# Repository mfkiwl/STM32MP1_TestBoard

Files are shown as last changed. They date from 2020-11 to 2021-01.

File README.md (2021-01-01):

### STM32MP1 Embedded Linux breakout board ###

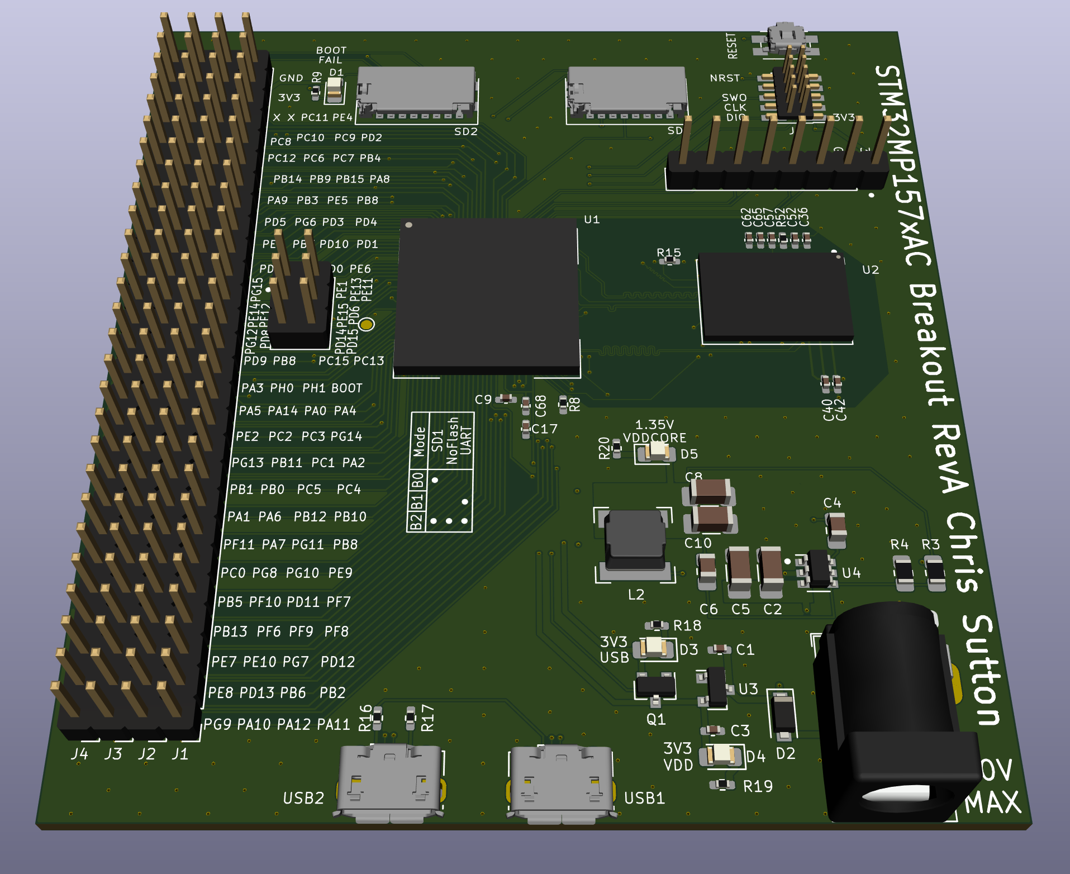
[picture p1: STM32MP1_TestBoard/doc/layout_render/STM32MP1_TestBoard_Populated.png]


[Bill of materials](STM32MP1_TestBoard/doc/bom/STM32MP1_TestBoard.csv)

[DataSheets](STM32MP1_TestBoard/doc/datasheets)

#### System Overview ####


#### Power Supply ####


#### MPU Power Supply ####


#### MPU DDR ####


#### MicroSD connectors ####


#### USB Connectors ####


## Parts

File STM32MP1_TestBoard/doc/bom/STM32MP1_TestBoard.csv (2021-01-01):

Reference | Value | Footprint | Datasheet | Mfr | PartNo
C17 | 1uF | Capacitor_SMD:C_0402_1005Metric_Pad0.74x0.62mm_HandSolder | https://datasheet.lcsc.com/szlcsc/1810201223_Taiyo-Yuden-LMK105BJ105KV-F_C87145.pdf | Taiyo Yuden | LMK105BJ105KV-F
C18 | 1uF | Capacitor_SMD:C_0402_1005Metric_Pad0.74x0.62mm_HandSolder | https://datasheet.lcsc.com/szlcsc/1810201223_Taiyo-Yuden-LMK105BJ105KV-F_C87145.pdf | Taiyo Yuden | LMK105BJ105KV-F
C21 | 1uF | Capacitor_SMD:C_0402_1005Metric_Pad0.74x0.62mm_HandSolder | https://datasheet.lcsc.com/szlcsc/1810201223_Taiyo-Yuden-LMK105BJ105KV-F_C87145.pdf | Taiyo Yuden | LMK105BJ105KV-F
C24 | 1uF | Capacitor_SMD:C_0402_1005Metric_Pad0.74x0.62mm_HandSolder | https://datasheet.lcsc.com/szlcsc/1810201223_Taiyo-Yuden-LMK105BJ105KV-F_C87145.pdf | Taiyo Yuden | LMK105BJ105KV-F
C27 | 1uF | Capacitor_SMD:C_0402_1005Metric_Pad0.74x0.62mm_HandSolder | https://datasheet.lcsc.com/szlcsc/1810201223_Taiyo-Yuden-LMK105BJ105KV-F_C87145.pdf | Taiyo Yuden | LMK105BJ105KV-F
C30 | 1uF | Capacitor_SMD:C_0402_1005Metric_Pad0.74x0.62mm_HandSolder | https://datasheet.lcsc.com/szlcsc/1810201223_Taiyo-Yuden-LMK105BJ105KV-F_C87145.pdf | Taiyo Yuden | LMK105BJ105KV-F
C32 | 1uF | Capacitor_SMD:C_0402_1005Metric_Pad0.74x0.62mm_HandSolder | https://datasheet.lcsc.com/szlcsc/1810201223_Taiyo-Yuden-LMK105BJ105KV-F_C87145.pdf | Taiyo Yuden | LMK105BJ105KV-F
C34 | 1uF | Capacitor_SMD:C_0402_1005Metric_Pad0.74x0.62mm_HandSolder | https://datasheet.lcsc.com/szlcsc/1810201223_Taiyo-Yuden-LMK105BJ105KV-F_C87145.pdf | Taiyo Yuden | LMK105BJ105KV-F
C35 | 1uF | Capacitor_SMD:C_0402_1005Metric_Pad0.74x0.62mm_HandSolder | https://datasheet.lcsc.com/szlcsc/1810201223_Taiyo-Yuden-LMK105BJ105KV-F_C87145.pdf | Taiyo Yuden | LMK105BJ105KV-F
C19 | 1uF | Capacitor_SMD:C_0402_1005Metric_Pad0.74x0.62mm_HandSolder | https://datasheet.lcsc.com/szlcsc/1810201223_Taiyo-Yuden-LMK105BJ105KV-F_C87145.pdf | Taiyo Yuden | LMK105BJ105KV-F
C22 | 1uF | Capacitor_SMD:C_0402_1005Metric_Pad0.74x0.62mm_HandSolder | https://datasheet.lcsc.com/szlcsc/1810201223_Taiyo-Yuden-LMK105BJ105KV-F_C87145.pdf | Taiyo Yuden | LMK105BJ105KV-F
C25 | 1uF | Capacitor_SMD:C_0402_1005Metric_Pad0.74x0.62mm_HandSolder | https://datasheet.lcsc.com/szlcsc/1810201223_Taiyo-Yuden-LMK105BJ105KV-F_C87145.pdf | Taiyo Yuden | LMK105BJ105KV-F
C28 | 1uF | Capacitor_SMD:C_0402_1005Metric_Pad0.74x0.62mm_HandSolder | https://datasheet.lcsc.com/szlcsc/1810201223_Taiyo-Yuden-LMK105BJ105KV-F_C87145.pdf | Taiyo Yuden | LMK105BJ105KV-F
C31 | 1uF | Capacitor_SMD:C_0402_1005Metric_Pad0.74x0.62mm_HandSolder | https://datasheet.lcsc.com/szlcsc/1810201223_Taiyo-Yuden-LMK105BJ105KV-F_C87145.pdf | Taiyo Yuden | LMK105BJ105KV-F
C33 | 1uF | Capacitor_SMD:C_0402_1005Metric_Pad0.74x0.62mm_HandSolder | https://datasheet.lcsc.com/szlcsc/1810201223_Taiyo-Yuden-LMK105BJ105KV-F_C87145.pdf | Taiyo Yuden | LMK105BJ105KV-F
C20 | 1uF | Capacitor_SMD:C_0402_1005Metric_Pad0.74x0.62mm_HandSolder | https://datasheet.lcsc.com/szlcsc/1810201223_Taiyo-Yuden-LMK105BJ105KV-F_C87145.pdf | Taiyo Yuden | LMK105BJ105KV-F
C23 | 1uF | Capacitor_SMD:C_0402_1005Metric_Pad0.74x0.62mm_HandSolder | https://datasheet.lcsc.com/szlcsc/1810201223_Taiyo-Yuden-LMK105BJ105KV-F_C87145.pdf | Taiyo Yuden | LMK105BJ105KV-F
C26 | 1uF | Capacitor_SMD:C_0402_1005Metric_Pad0.74x0.62mm_HandSolder | https://datasheet.lcsc.com/szlcsc/1810201223_Taiyo-Yuden-LMK105BJ105KV-F_C87145.pdf | Taiyo Yuden | LMK105BJ105KV-F
C29 | 1uF | Capacitor_SMD:C_0402_1005Metric_Pad0.74x0.62mm_HandSolder | https://datasheet.lcsc.com/szlcsc/1810201223_Taiyo-Yuden-LMK105BJ105KV-F_C87145.pdf | Taiyo Yuden | LMK105BJ105KV-F
L3 | LQM18FN4R7M00D | Inductor_SMD:L_0201_0603Metric_Pad0.64x0.40mm_HandSolder | https://www.mouser.co.uk/datasheet/2/281/JELF243B-0012-1633801.pdf | ~ | ~
C14 | 1uF | Capacitor_SMD:C_0402_1005Metric_Pad0.74x0.62mm_HandSolder | https://datasheet.lcsc.com/szlcsc/1810201223_Taiyo-Yuden-LMK105BJ105KV-F_C87145.pdf | Taiyo Yuden | LMK105BJ105KV-F
C12 | 1uF | Capacitor_SMD:C_0402_1005Metric_Pad0.74x0.62mm_HandSolder | https://datasheet.lcsc.com/szlcsc/1810201223_Taiyo-Yuden-LMK105BJ105KV-F_C87145.pdf | Taiyo Yuden | LMK105BJ105KV-F
JP4 | Jumper_NC_Small | Jumper:SolderJumper-2_P1.3mm_Bridged_Pad1.0x1.5mm | ~ | ~ | ~
C69 | 2.2uF | Capacitor_SMD:C_0402_1005Metric_Pad0.74x0.62mm_HandSolder | https://datasheet.lcsc.com/szlcsc/1810201223_Taiyo-Yuden-LMK105BJ105KV-F_C87145.pdf | Taiyo Yuden | LMK105BJ105KV-F
C70 | 1uF | Capacitor_SMD:C_0402_1005Metric_Pad0.74x0.62mm_HandSolder | https://datasheet.lcsc.com/szlcsc/1810201223_Taiyo-Yuden-LMK105BJ105KV-F_C87145.pdf | Taiyo Yuden | LMK105BJ105KV-F
C68 | 1uF | Capacitor_SMD:C_0402_1005Metric_Pad0.74x0.62mm_HandSolder | https://datasheet.lcsc.com/szlcsc/1810201223_Taiyo-Yuden-LMK105BJ105KV-F_C87145.pdf | Taiyo Yuden | LMK105BJ105KV-F
C7 | 2.2uF | Capacitor_SMD:C_0402_1005Metric_Pad0.74x0.62mm_HandSolder | https://datasheet.lcsc.com/szlcsc/1810201223_Taiyo-Yuden-LMK105BJ105KV-F_C87145.pdf | Taiyo Yuden | LMK105BJ105KV-F
C9 | 2.2uF | Capacitor_SMD:C_0402_1005Metric_Pad0.74x0.62mm_HandSolder | https://datasheet.lcsc.com/szlcsc/1810201223_Taiyo-Yuden-LMK105BJ105KV-F_C87145.pdf | Taiyo Yuden | LMK105BJ105KV-F
U1 | STM32MP157xAC | STM32MP151_LFBGA:BGA-361_19x19_16.0x16.0mm | https://www.st.com/resource/en/datasheet/stm32mp151c.pdf | ~ | ~
TP1 | TestPoint | TestPoint:TestPoint_Pad_D1.0mm | ~ | ~ | ~
U4 | TPS54202DDC | Package_TO_SOT_SMD:SOT-23-6 | http://www.ti.com/lit/ds/symlink/tps54202.pdf | Texas Instruments | TPS54202DDCR
C2 | 22uF | Capacitor_SMD:C_1206_3216Metric_Pad1.33x1.80mm_HandSolder | https://www.mouser.co.uk/datasheet/2/212/KEM_C1006_X5R_SMD-1103249.pdf | Kemet | C1206C226M8PACTU
C8 | 22uF | Capacitor_SMD:C_1206_3216Metric_Pad1.33x1.80mm_HandSolder | https://www.mouser.co.uk/datasheet/2/212/KEM_C1006_X5R_SMD-1103249.pdf | Kemet | C1206C226M8PACTU
C10 | 22uF | Capacitor_SMD:C_1206_3216Metric_Pad1.33x1.80mm_HandSolder | https://www.mouser.co.uk/datasheet/2/212/KEM_C1006_X5R_SMD-1103249.pdf | Kemet | C1206C226M8PACTU
L2 | 4.7uH | Inductor_SMD:L_Bourns-SRN6028 | https://datasheet.lcsc.com/szlcsc/1808311234_SXN-Shun-Xiang-Nuo-Elec-SMNR6028-4R7MT_C266428.pdf | Shun Xiang Nuo Elec | SMNR6028-4R7MT
C4 | 100nF | Capacitor_SMD:C_0805_2012Metric_Pad1.18x1.45mm_HandSolder | ~ | ~ | ~
C6 | 56pF | Capacitor_SMD:C_0805_2012Metric_Pad1.18x1.45mm_HandSolder | ~ | ~ | ~
R3 | 100K | Resistor_SMD:R_0805_2012Metric_Pad1.20x1.40mm_HandSolder | ~ | ~ | ~
R4 | 82K | Resistor_SMD:R_0805_2012Metric_Pad1.20x1.40mm_HandSolder | ~ | ~ | ~
Q1 | DMG2302U | Package_TO_SOT_SMD:SOT-23 | https://datasheet.octopart.com/DMG2302U-7-Diodes-Inc.-datasheet-103571615.pdf | DiodesInc | DMG2302U
U3 | SE8233X2 | Package_TO_SOT_SMD:SOT-23 | https://datasheet.lcsc.com/szlcsc/1912111437_Seaward-Elec-SE8233X2_C437587.pdf | ~ | ~
C1 | 1uF | Capacitor_SMD:C_0402_1005Metric_Pad0.74x0.62mm_HandSolder | ~ | ~ | ~
C3 | 10uF | Capacitor_SMD:C_0402_1005Metric_Pad0.74x0.62mm_HandSolder | ~ | ~ | ~
C5 | 22uF | Capacitor_SMD:C_1206_3216Metric_Pad1.33x1.80mm_HandSolder | https://www.mouser.co.uk/datasheet/2/212/KEM_C1006_X5R_SMD-1103249.pdf | Kemet | C1206C226M8PACTU
J9 | Barrel_Jack | Connector_BarrelJack:BarrelJack_Horizontal | ~ | ~ | ~
D2 | D_Schottky | Diode_SMD:D_SOD-123F | ~ | ~ | ~
D4 | LED | LED_SMD:LED_0805_2012Metric_Pad1.15x1.40mm_HandSolder | ~ | ~ | ~
R19 | 2K2 | Resistor_SMD:R_0402_1005Metric_Pad0.72x0.64mm_HandSolder | ~ | ~ | ~
D5 | LED | LED_SMD:LED_0805_2012Metric_Pad1.15x1.40mm_HandSolder | ~ | ~ | ~
R20 | 2K2 | Resistor_SMD:R_0402_1005Metric_Pad0.72x0.64mm_HandSolder | ~ | ~ | ~
D3 | LED | LED_SMD:LED_0805_2012Metric_Pad1.15x1.40mm_HandSolder | ~ | ~ | ~
R18 | 2K2 | Resistor_SMD:R_0402_1005Metric_Pad0.72x0.64mm_HandSolder | ~ | ~ | ~
SW2 | SW_SPST | Button_Switch_SMD:Panasonic_EVQPUK_EVQPUB | https://industrial.panasonic.com/cdbs/www-data/pdf/ATK0000/ATK0000C382.pdf | ~ | ~
C13 | 10nF | Capacitor_SMD:C_0402_1005Metric_Pad0.74x0.62mm_HandSolder | ~ | ~ | ~
C15 | 10nF | Capacitor_SMD:C_0402_1005Metric_Pad0.74x0.62mm_HandSolder | ~ | ~ | ~
JP5 | Jumper_NC_Small | Jumper:SolderJumper-2_P1.3mm_Bridged_RoundedPad1.0x1.5mm | ~ | ~ | ~
J6 | Conn_02x05_Odd_Even | Connector_PinHeader_1.27mm:PinHeader_2x05_P1.27mm_Vertical_SMD | https://docs.rs-online.com/75e3/0900766b8142184e.pdf | Amphenol ICC | 20021121-00010C4LF
J5 | Conn_02x03_Odd_Even | Connector_PinHeader_2.54mm:PinHeader_2x03_P2.54mm_Vertical | ~ | ~ | ~
R7 | 1K | Resistor_SMD:R_0402_1005Metric_Pad0.72x0.64mm_HandSolder | ~ | ~ | ~
R5 | 1K | Resistor_SMD:R_0402_1005Metric_Pad0.72x0.64mm_HandSolder | ~ | ~ | ~
R1 | 1K | Resistor_SMD:R_0402_1005Metric_Pad0.72x0.64mm_HandSolder | ~ | ~ | ~
R8 | 3K | Resistor_SMD:R_0402_1005Metric_Pad0.72x0.64mm_HandSolder | ~ | ~ | ~
D1 | LED | LED_SMD:LED_0805_2012Metric_Pad1.15x1.40mm_HandSolder | ~ | ~ | ~
R9 | 1K | Resistor_SMD:R_0402_1005Metric_Pad0.72x0.64mm_HandSolder | ~ | ~ | ~
J1 | Conn_01x27 | Connector_PinHeader_2.54mm:PinHeader_1x27_P2.54mm_Vertical | ~ | ~ | ~
J3 | Conn_01x27 | Connector_PinHeader_2.54mm:PinHeader_1x27_P2.54mm_Vertical | ~ | ~ | ~
J4 | Conn_01x27 | Connector_PinHeader_2.54mm:PinHeader_1x27_P2.54mm_Vertical | ~ | ~ | ~
J2 | Conn_01x27 | Connector_PinHeader_2.54mm:PinHeader_1x27_P2.54mm_Vertical | ~ | ~ | ~
J7 | Conn_01x08 | Connector_PinHeader_2.54mm:PinHeader_1x08_P2.54mm_Vertical | ~ | ~ | ~
R12 | 47K | Resistor_SMD:R_0402_1005Metric_Pad0.72x0.64mm_HandSolder | ~ | ~ | ~
R13 | 47K | Resistor_SMD:R_0402_1005Metric_Pad0.72x0.64mm_HandSolder | ~ | ~ | ~
R40 | 47K | Resistor_SMD:R_0402_1005Metric_Pad0.72x0.64mm_HandSolder | ~ | ~ | ~
R41 | 47K | Resistor_SMD:R_0402_1005Metric_Pad0.72x0.64mm_HandSolder | ~ | ~ | ~
R42 | 47K | Resistor_SMD:R_0402_1005Metric_Pad0.72x0.64mm_HandSolder | ~ | ~ | ~
J12 | Micro_SD_Card | Molex_SDIO:Molex_SDIO_475710001 | https://www.molex.com/molex/products/part-detail/memory_card_socket/0475710001 | Molex | 475710001
J14 | USB_B_Micro | Connector_USB:USB_Micro-B_Molex-105017-0001 | ~ | ~ | ~
J8 | USB_B_Micro | Connector_USB:USB_Micro-B_Molex-105017-0001 | ~ | ~ | ~
R16 | 0R | Resistor_SMD:R_0402_1005Metric_Pad0.72x0.64mm_HandSolder | ~ | ~ | ~
R17 | 0R | Resistor_SMD:R_0402_1005Metric_Pad0.72x0.64mm_HandSolder | ~ | ~ | ~
R43 | 47K | Resistor_SMD:R_0402_1005Metric_Pad0.72x0.64mm_HandSolder | ~ | ~ | ~
R44 | 47K | Resistor_SMD:R_0402_1005Metric_Pad0.72x0.64mm_HandSolder | ~ | ~ | ~
R45 | 47K | Resistor_SMD:R_0402_1005Metric_Pad0.72x0.64mm_HandSolder | ~ | ~ | ~
R46 | 47K | Resistor_SMD:R_0402_1005Metric_Pad0.72x0.64mm_HandSolder | ~ | ~ | ~
R47 | 47K | Resistor_SMD:R_0402_1005Metric_Pad0.72x0.64mm_HandSolder | ~ | ~ | ~
J13 | Micro_SD_Card | Molex_SDIO:Molex_SDIO_475710001 | https://www.molex.com/molex/products/part-detail/memory_card_socket/0475710001 | Molex | 475710001
U2 | MT41K256M16TW-107 | Package_BGA:BGA-96_9.0x13.0mm_Layout2x3x16_P0.8mm | https://www.mouser.co.uk/datasheet/2/671/4Gb_DDR3L-1283964.pdf | Micron | MT41K256M16TW-107
C36 | 100nF | Capacitor_SMD:C_0402_1005Metric_Pad0.74x0.62mm_HandSolder | ~ | ~ | ~
R10 | 240R | Resistor_SMD:R_0402_1005Metric_Pad0.72x0.64mm_HandSolder | ~ | ~ | ~
R11 | 240R | Resistor_SMD:R_0402_1005Metric_Pad0.72x0.64mm_HandSolder | ~ | ~ | ~
R6 | 10K | Resistor_SMD:R_0402_1005Metric_Pad0.72x0.64mm_HandSolder | ~ | ~ | ~
R15 | 10K | Resistor_SMD:R_0402_1005Metric_Pad0.72x0.64mm_HandSolder | ~ | ~ | ~
R14 | 100R | Resistor_SMD:R_0402_1005Metric_Pad0.72x0.64mm_HandSolder | ~ | ~ | ~
C52 | 100nF | Capacitor_SMD:C_0402_1005Metric_Pad0.74x0.62mm_HandSolder | ~ | ~ | ~
C57 | 100nF | Capacitor_SMD:C_0402_1005Metric_Pad0.74x0.62mm_HandSolder | ~ | ~ | ~
C62 | 100nF | Capacitor_SMD:C_0402_1005Metric_Pad0.74x0.62mm_HandSolder | ~ | ~ | ~
C65 | 100nF | Capacitor_SMD:C_0402_1005Metric_Pad0.74x0.62mm_HandSolder | ~ | ~ | ~
C43 | 100nF | Capacitor_SMD:C_0402_1005Metric_Pad0.74x0.62mm_HandSolder | ~ | ~ | ~
C42 | 100nF | Capacitor_SMD:C_0402_1005Metric_Pad0.74x0.62mm_HandSolder | ~ | ~ | ~
C41 | 100nF | Capacitor_SMD:C_0402_1005Metric_Pad0.74x0.62mm_HandSolder | ~ | ~ | ~
C40 | 100nF | Capacitor_SMD:C_0402_1005Metric_Pad0.74x0.62mm_HandSolder | ~ | ~ | ~
R2 | 1K | Resistor_SMD:R_0402_1005Metric_Pad0.72x0.64mm_HandSolder | ~ | ~ | ~
R52 | 1K | Resistor_SMD:R_0402_1005Metric_Pad0.72x0.64mm_HandSolder | ~ | ~ | ~

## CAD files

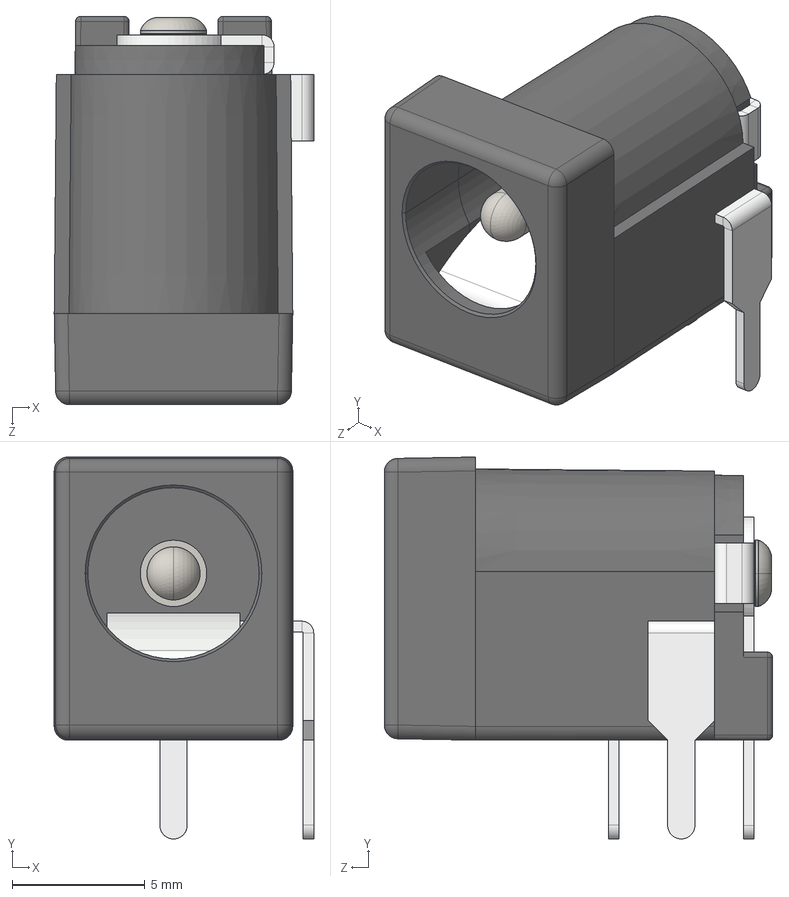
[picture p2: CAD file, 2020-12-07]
STM32MP1_TestBoard/doc/3d/DC Power Jack 5.5mm x 2.1mm.STEP
9.77 x 14.4 x 14.6 mm

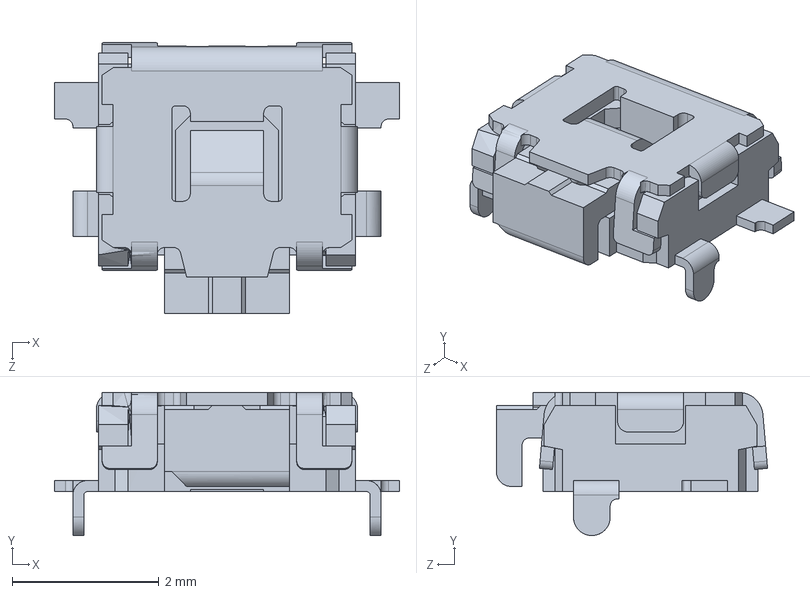
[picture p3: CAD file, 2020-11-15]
STM32MP1_TestBoard/doc/3d/EVQ-9P7_P34-01P.STEP
4.70 x 1.95 x 3.69 mm

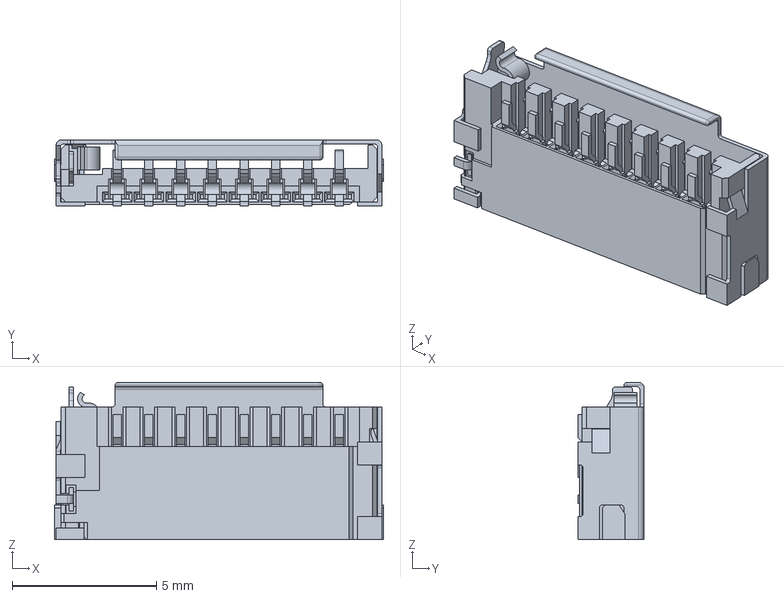
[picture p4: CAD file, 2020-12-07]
STM32MP1_TestBoard/doc/3d/475710001.stp
11.4 x 2.30 x 5.45 mm

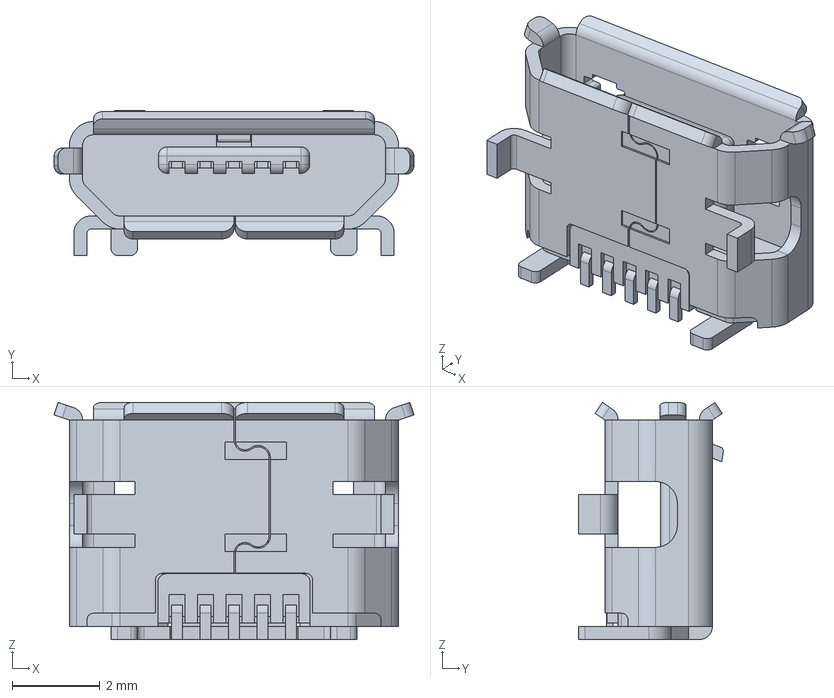
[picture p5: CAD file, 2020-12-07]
STM32MP1_TestBoard/doc/3d/1050170001.stp
8.20 x 3.30 x 5.40 mm

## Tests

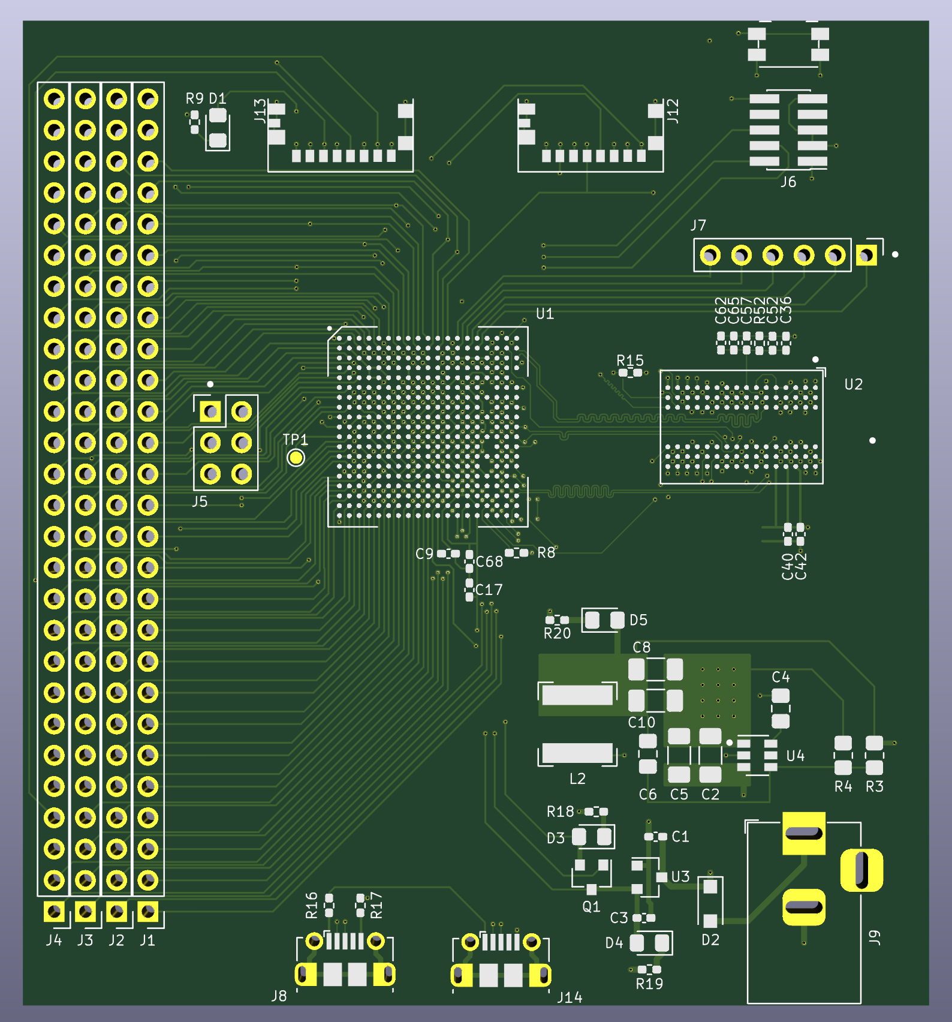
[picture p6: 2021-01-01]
STM32MP1_TestBoard/doc/layout_render/STM32MP1_TestBoard_Front.png

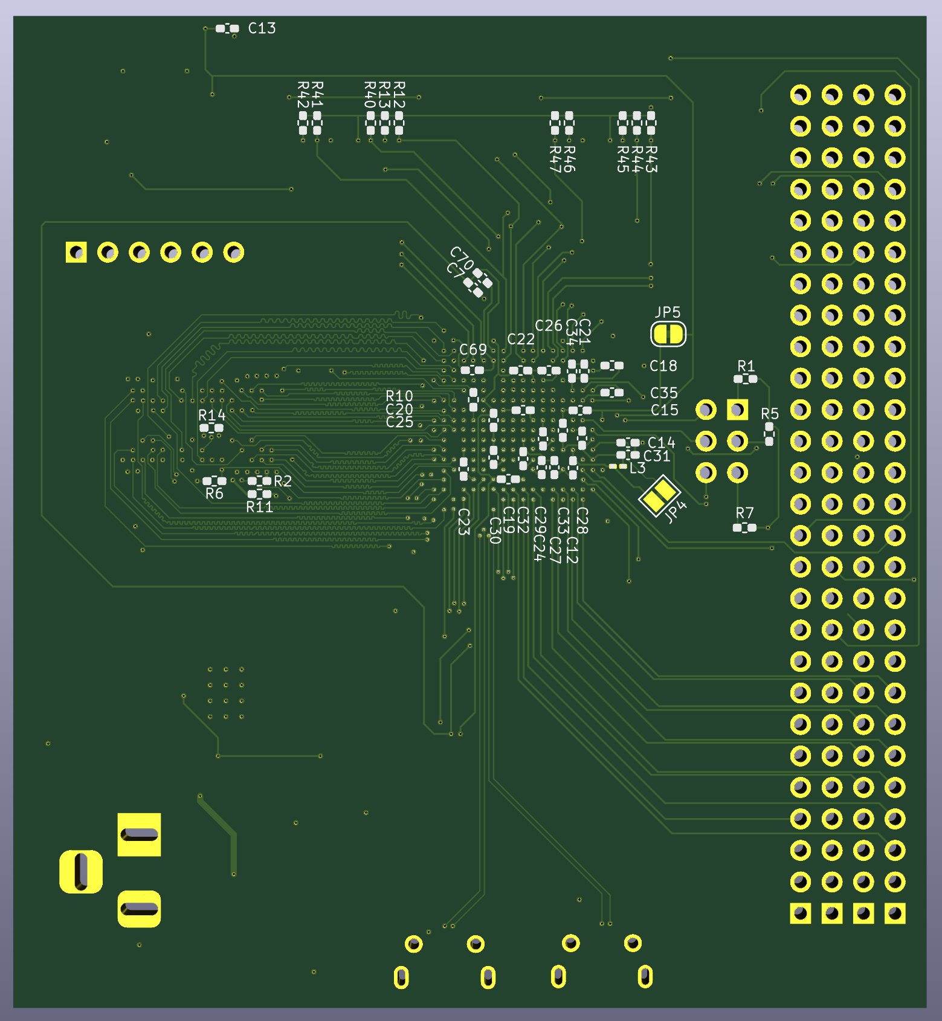
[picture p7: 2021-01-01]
STM32MP1_TestBoard/doc/layout_render/STM32MP1_TestBoard_Back.png

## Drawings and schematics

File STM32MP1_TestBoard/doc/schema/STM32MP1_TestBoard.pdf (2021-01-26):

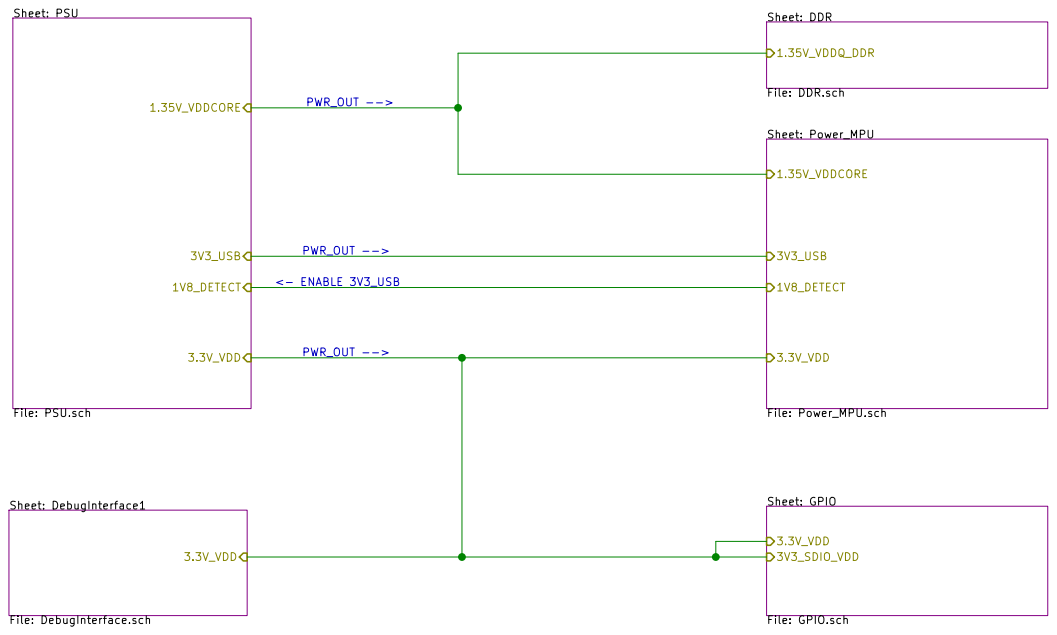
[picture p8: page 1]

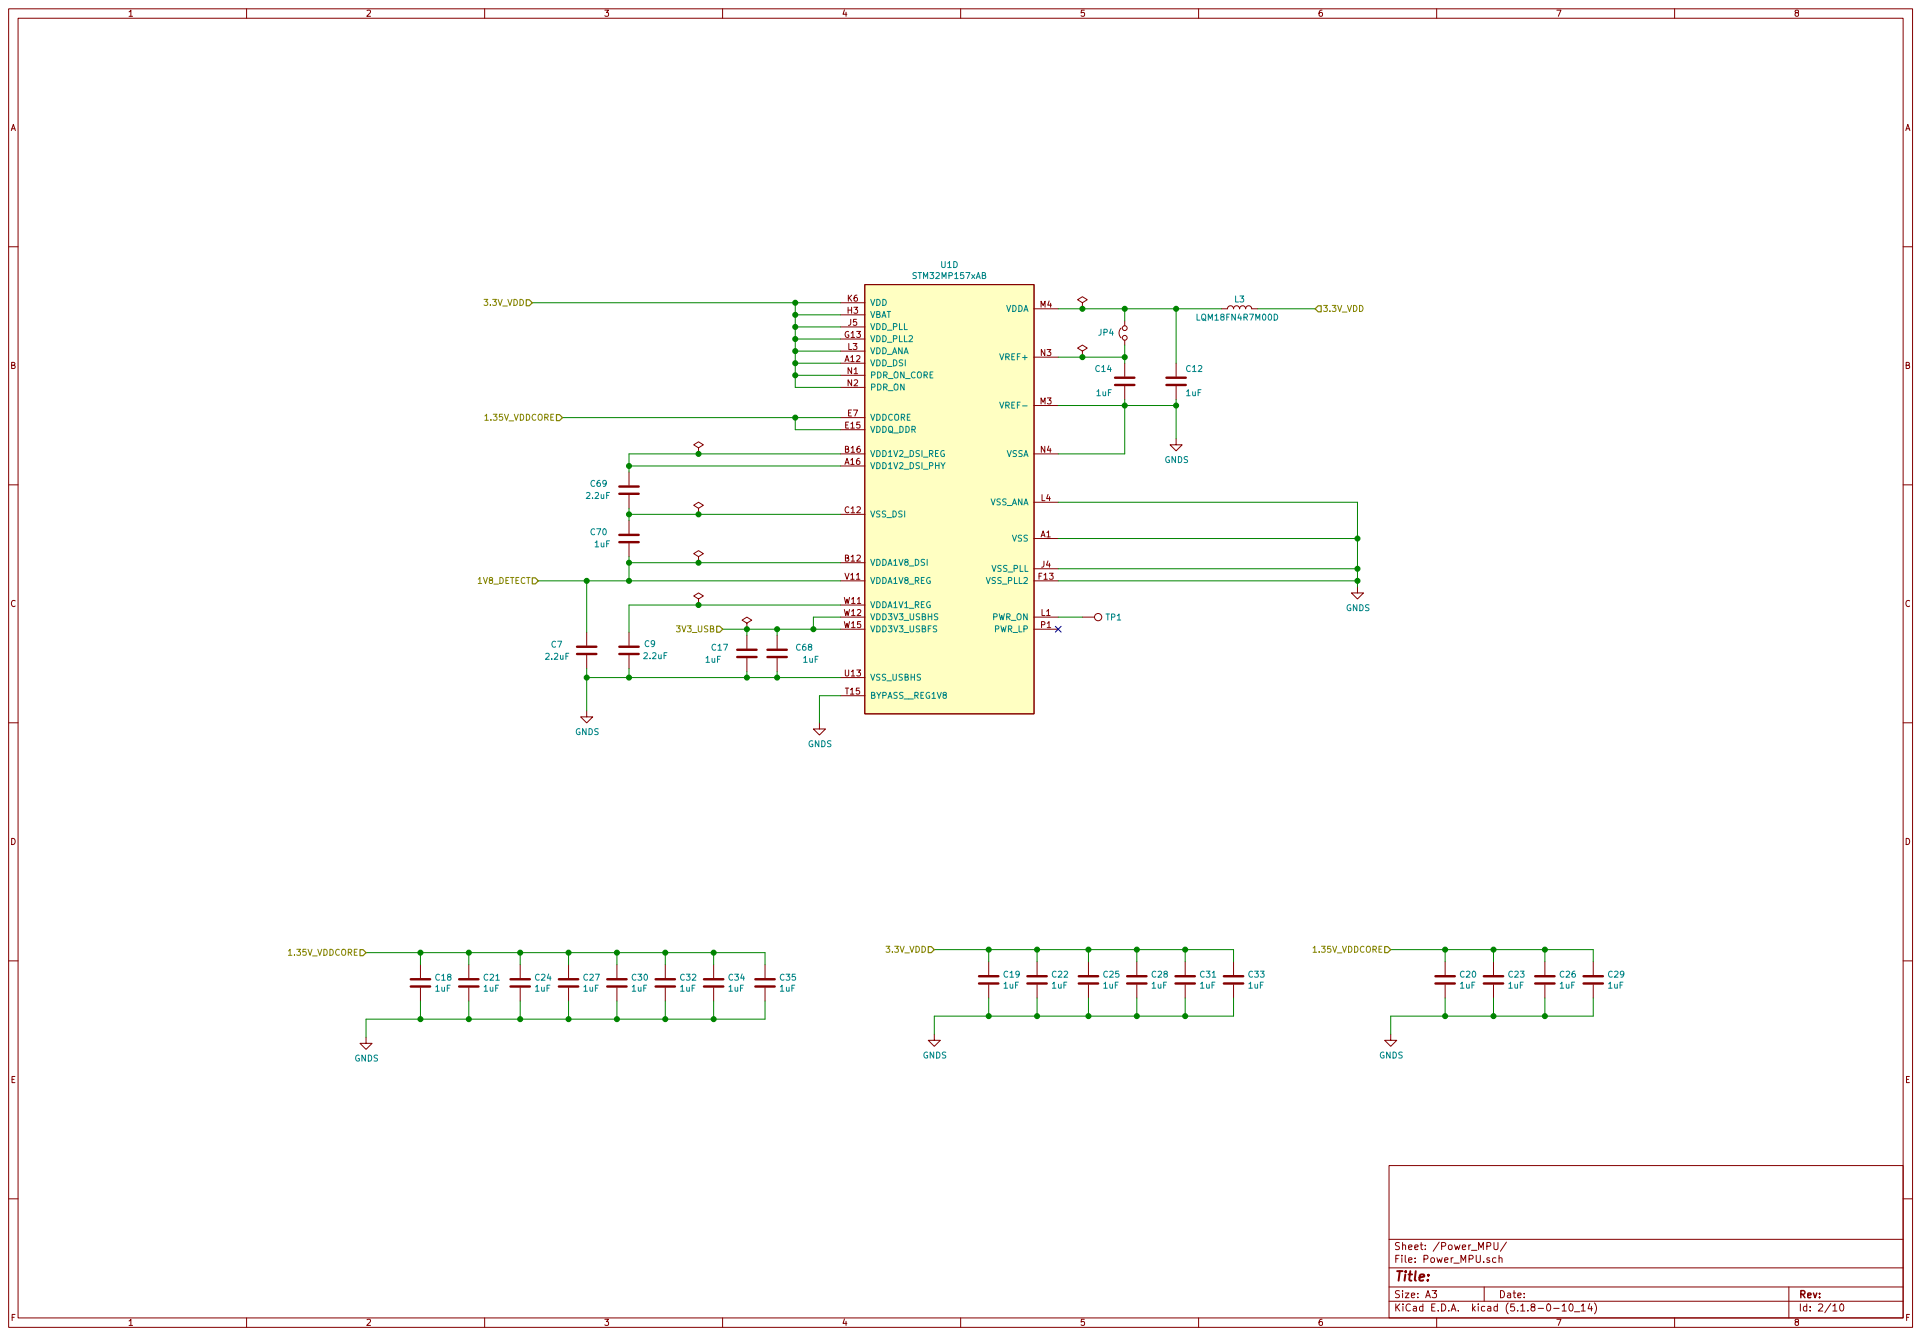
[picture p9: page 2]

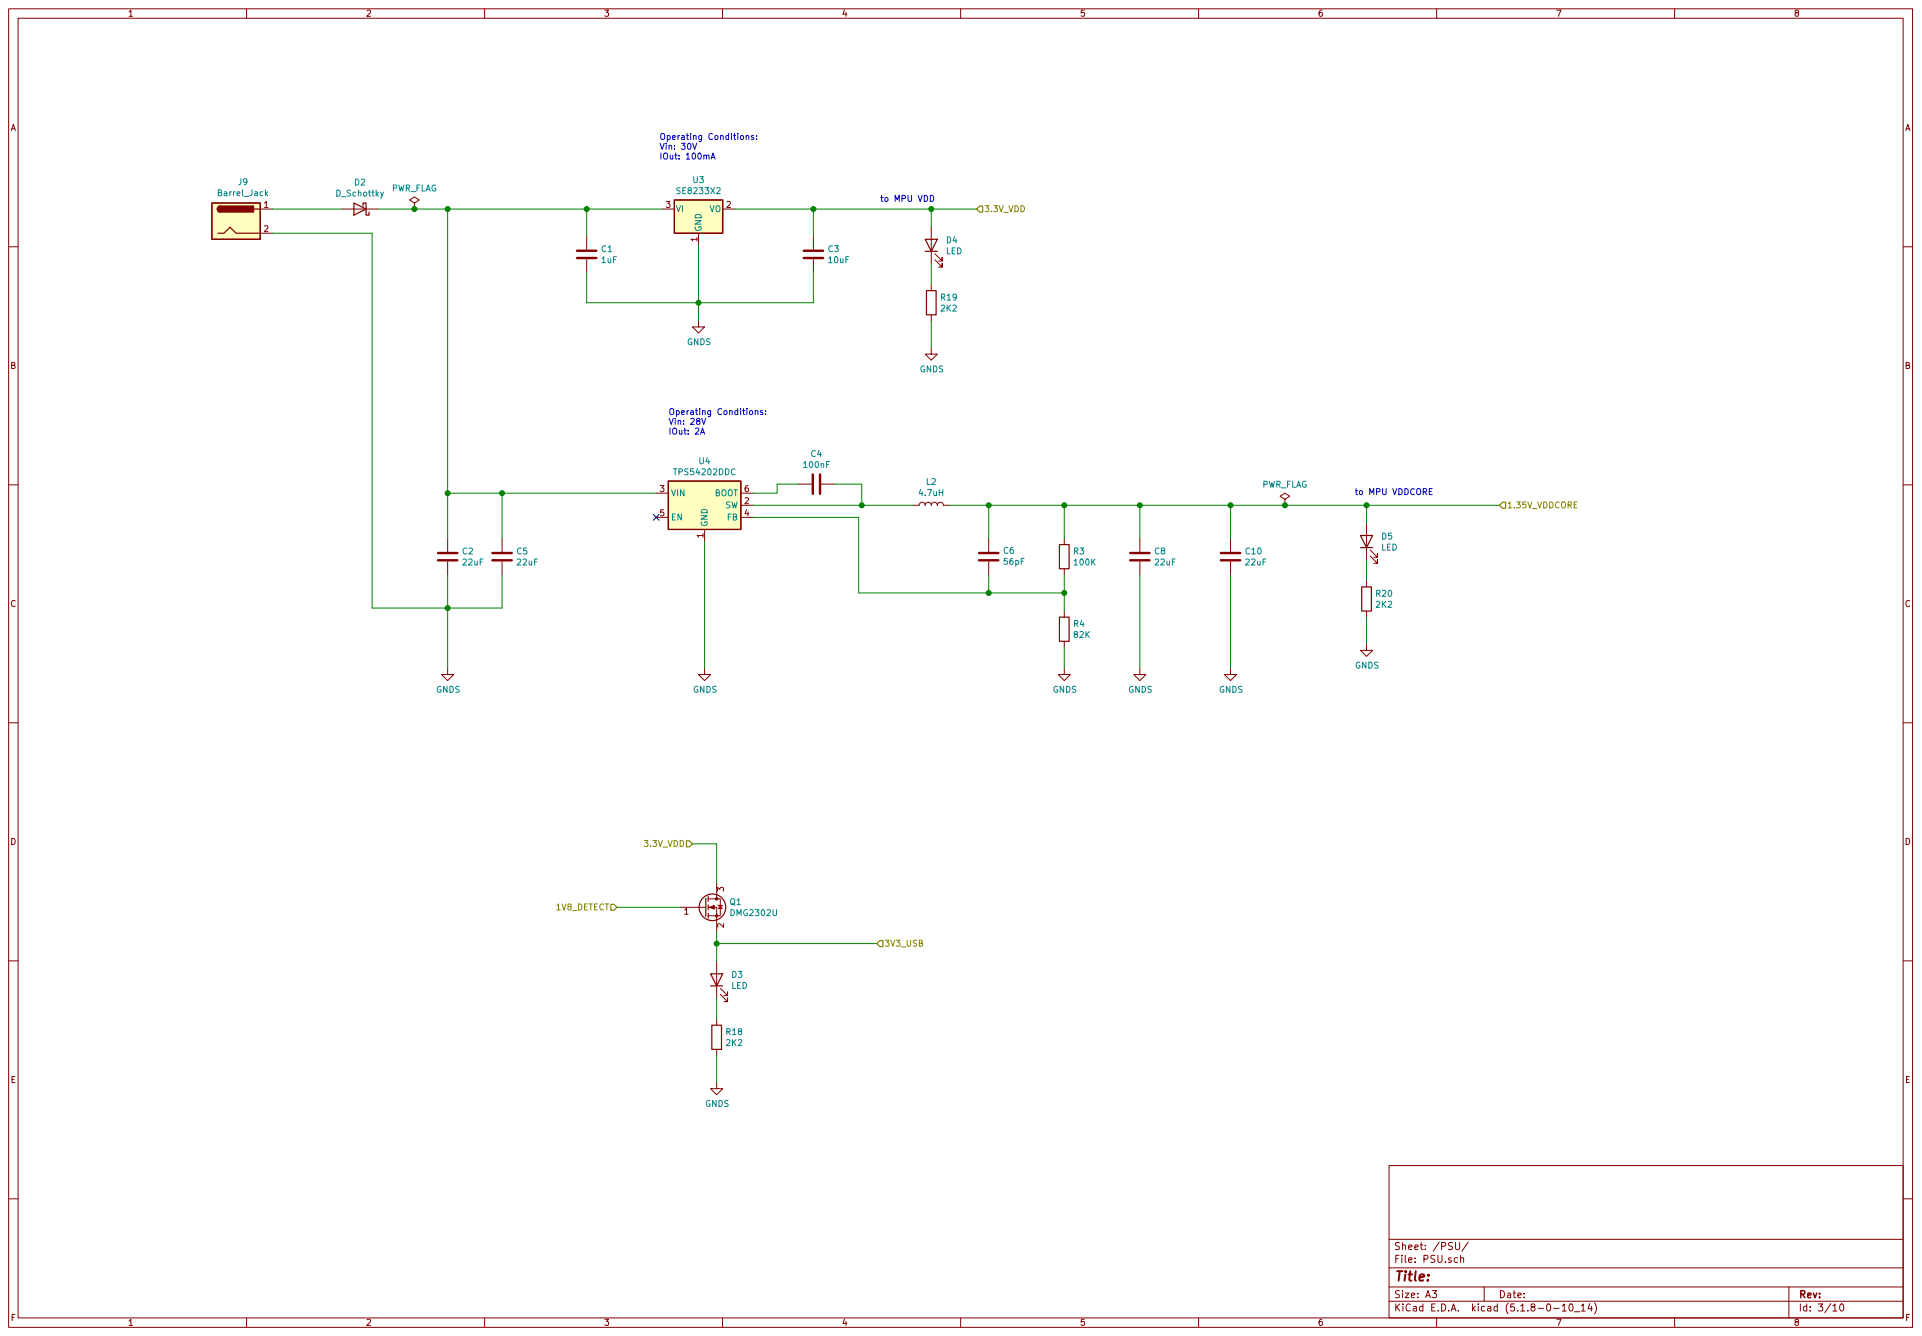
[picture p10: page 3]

IOut: 2A Operating Conditions: Vin: 30V

1 SW 2 VIN 3 FB 4 EN 5 BOOT 6 U4 TPS54202DDC

Id: 3/10 Title: File: PSU.sch Sheet: /PSU/ GND

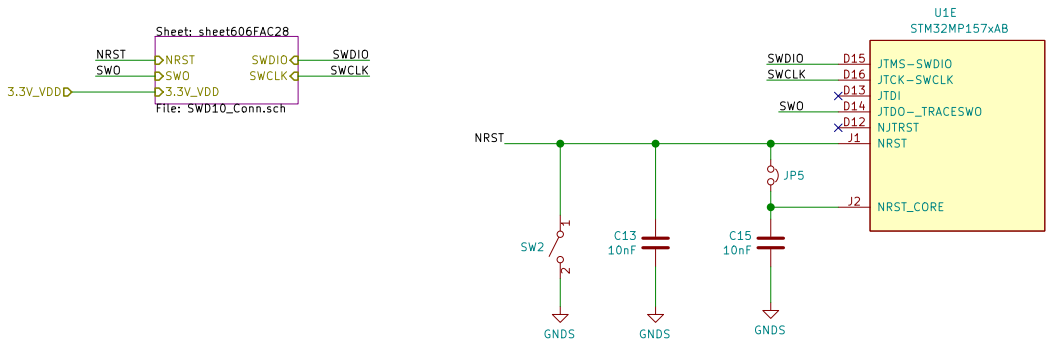
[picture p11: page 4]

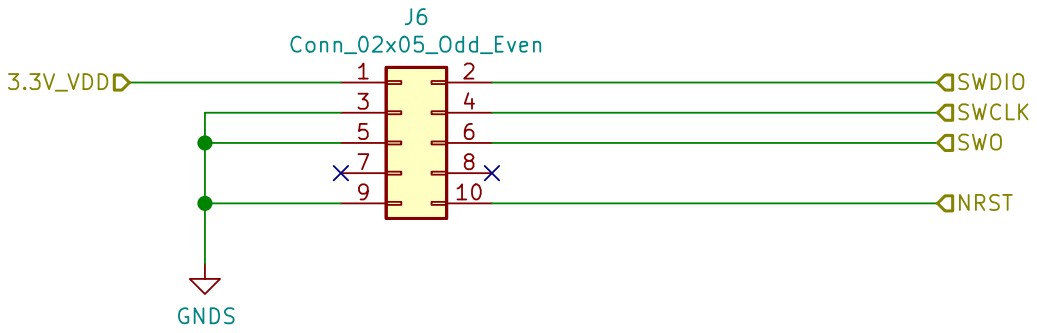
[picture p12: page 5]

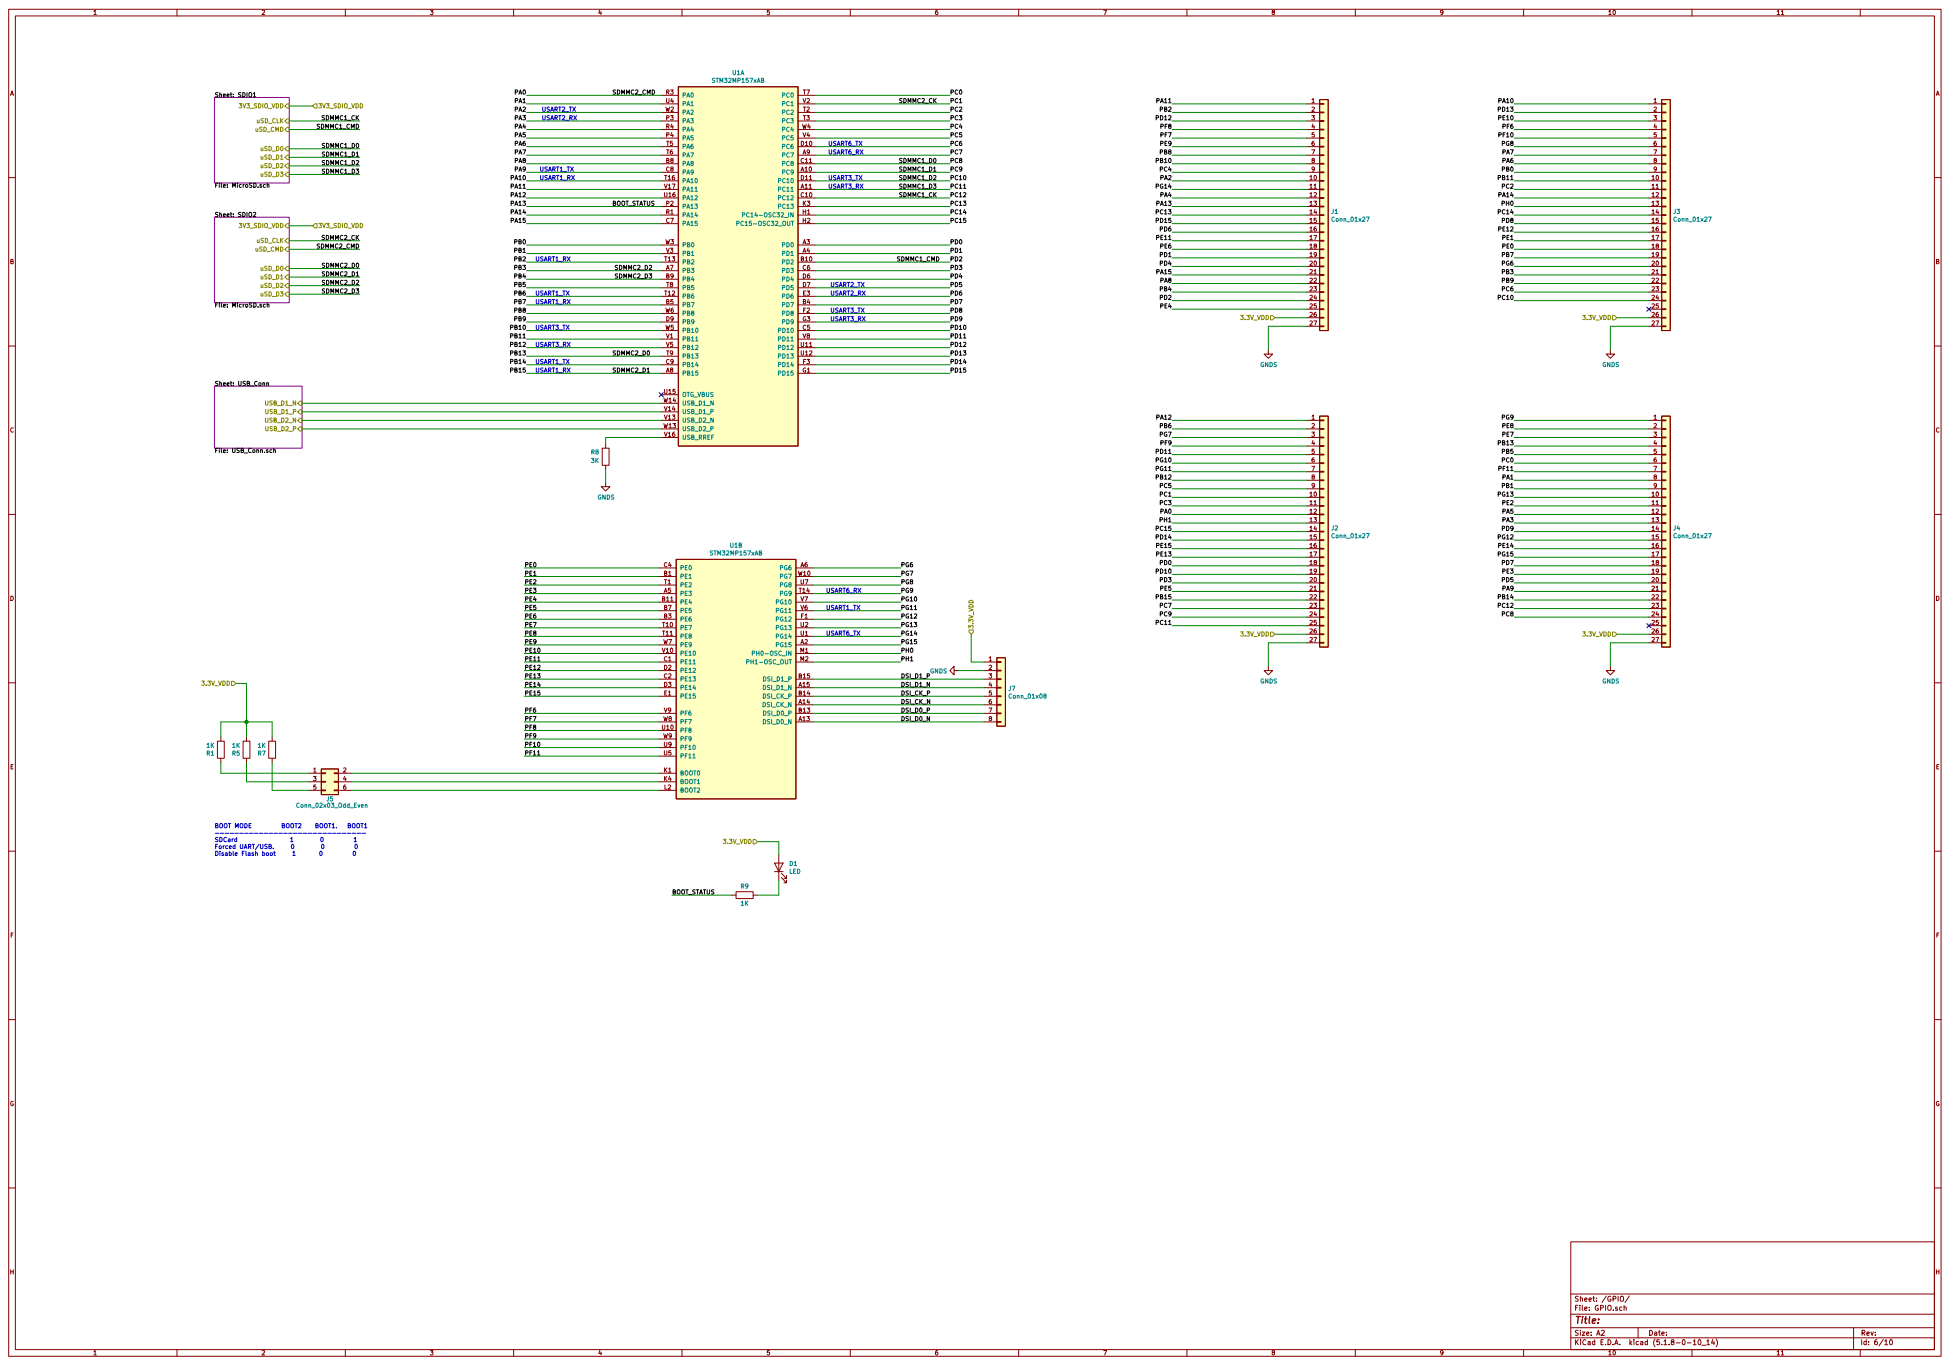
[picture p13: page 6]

Sheet: SDIO1 File: MicroSD.sch

Id: 6/10 Title: File: GPIO.sch Sheet: /GPIO/

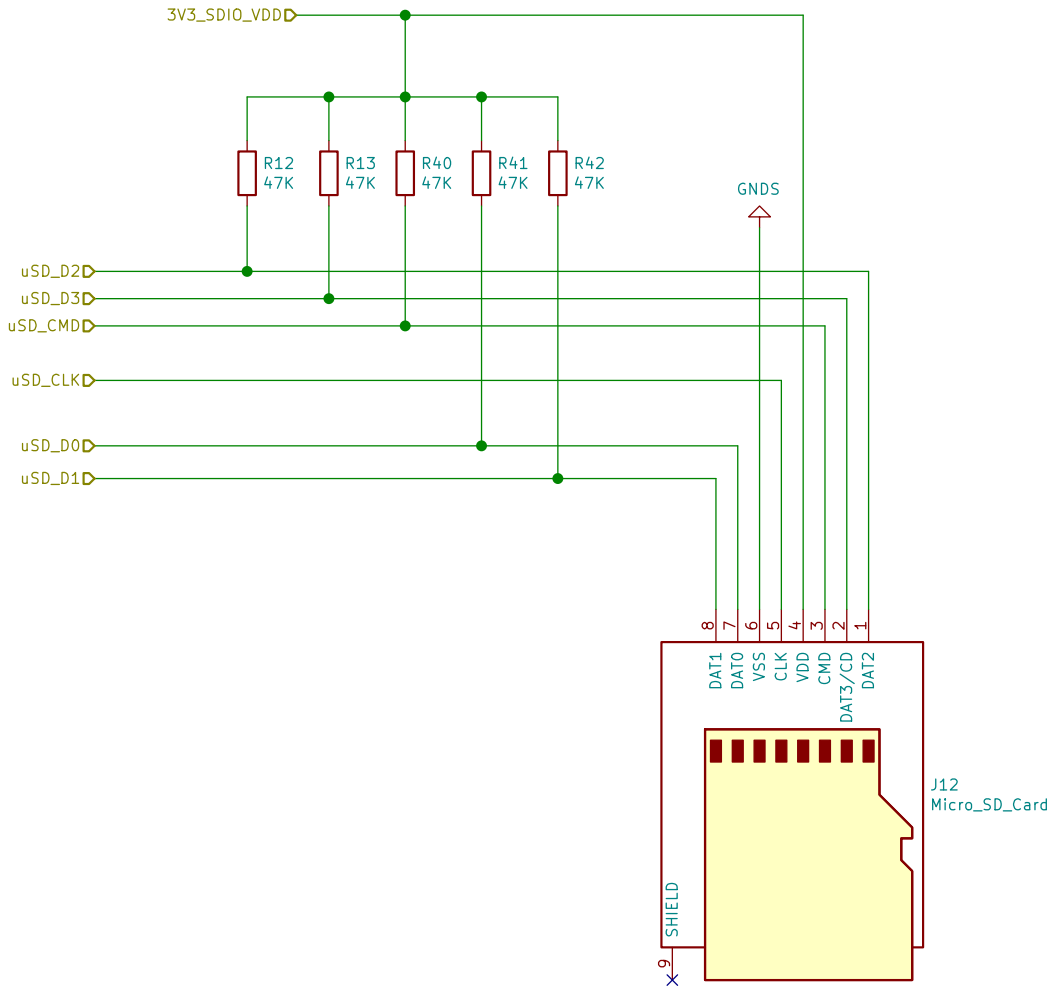
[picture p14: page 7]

1 DAT3/CD
Id: 7/10 Title: File: MicroSD.sch Sheet: /GPIO/SDIO1/ DAT2

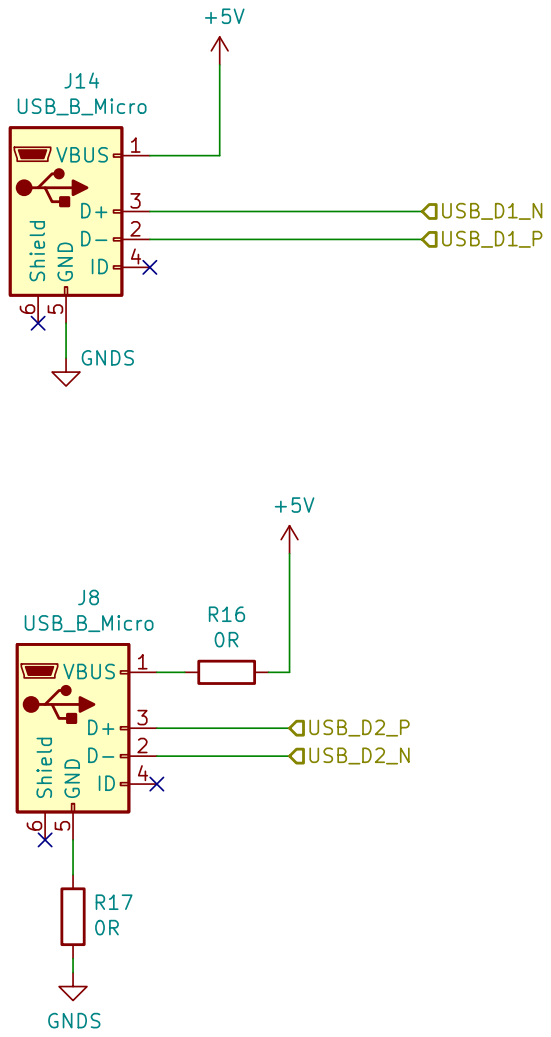
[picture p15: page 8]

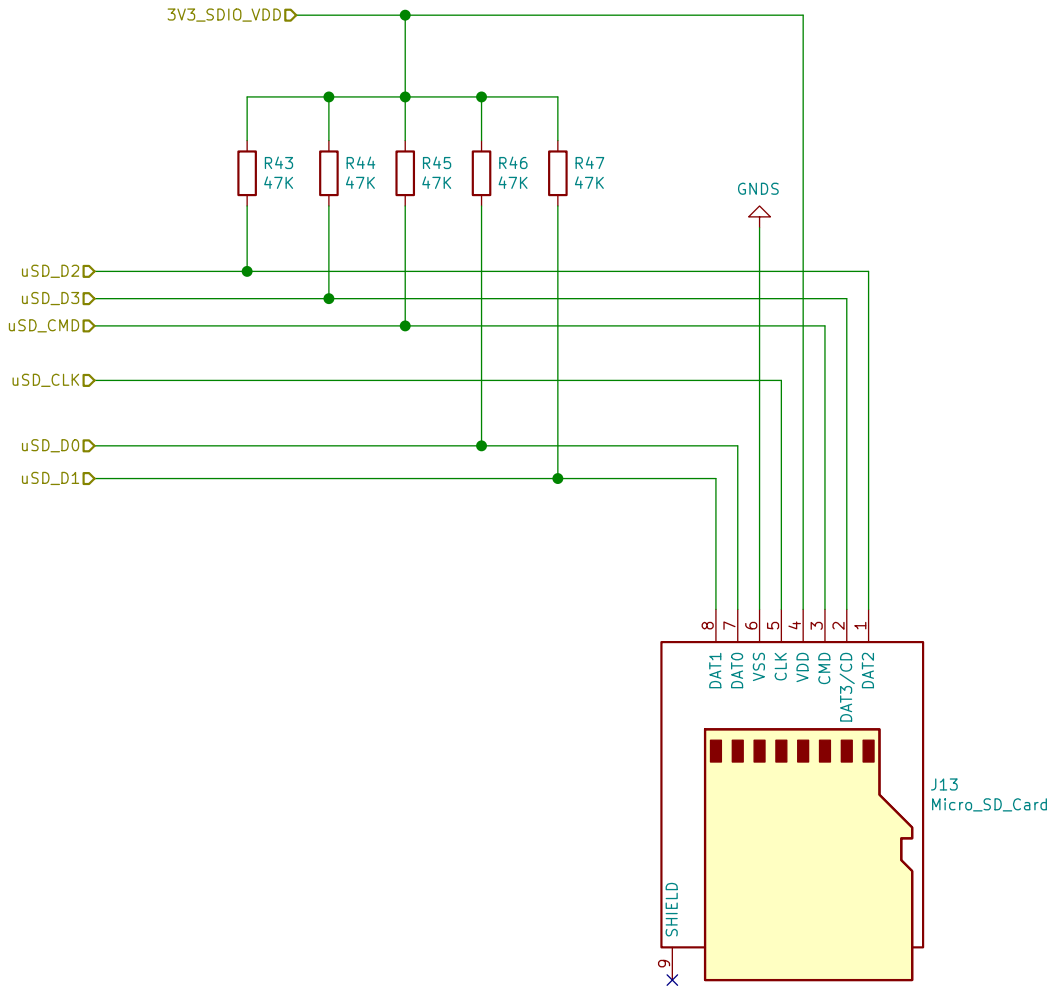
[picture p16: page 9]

1 DAT3/CD
Id: 9/10 Title: File: MicroSD.sch Sheet: /GPIO/SDIO2/ DAT2

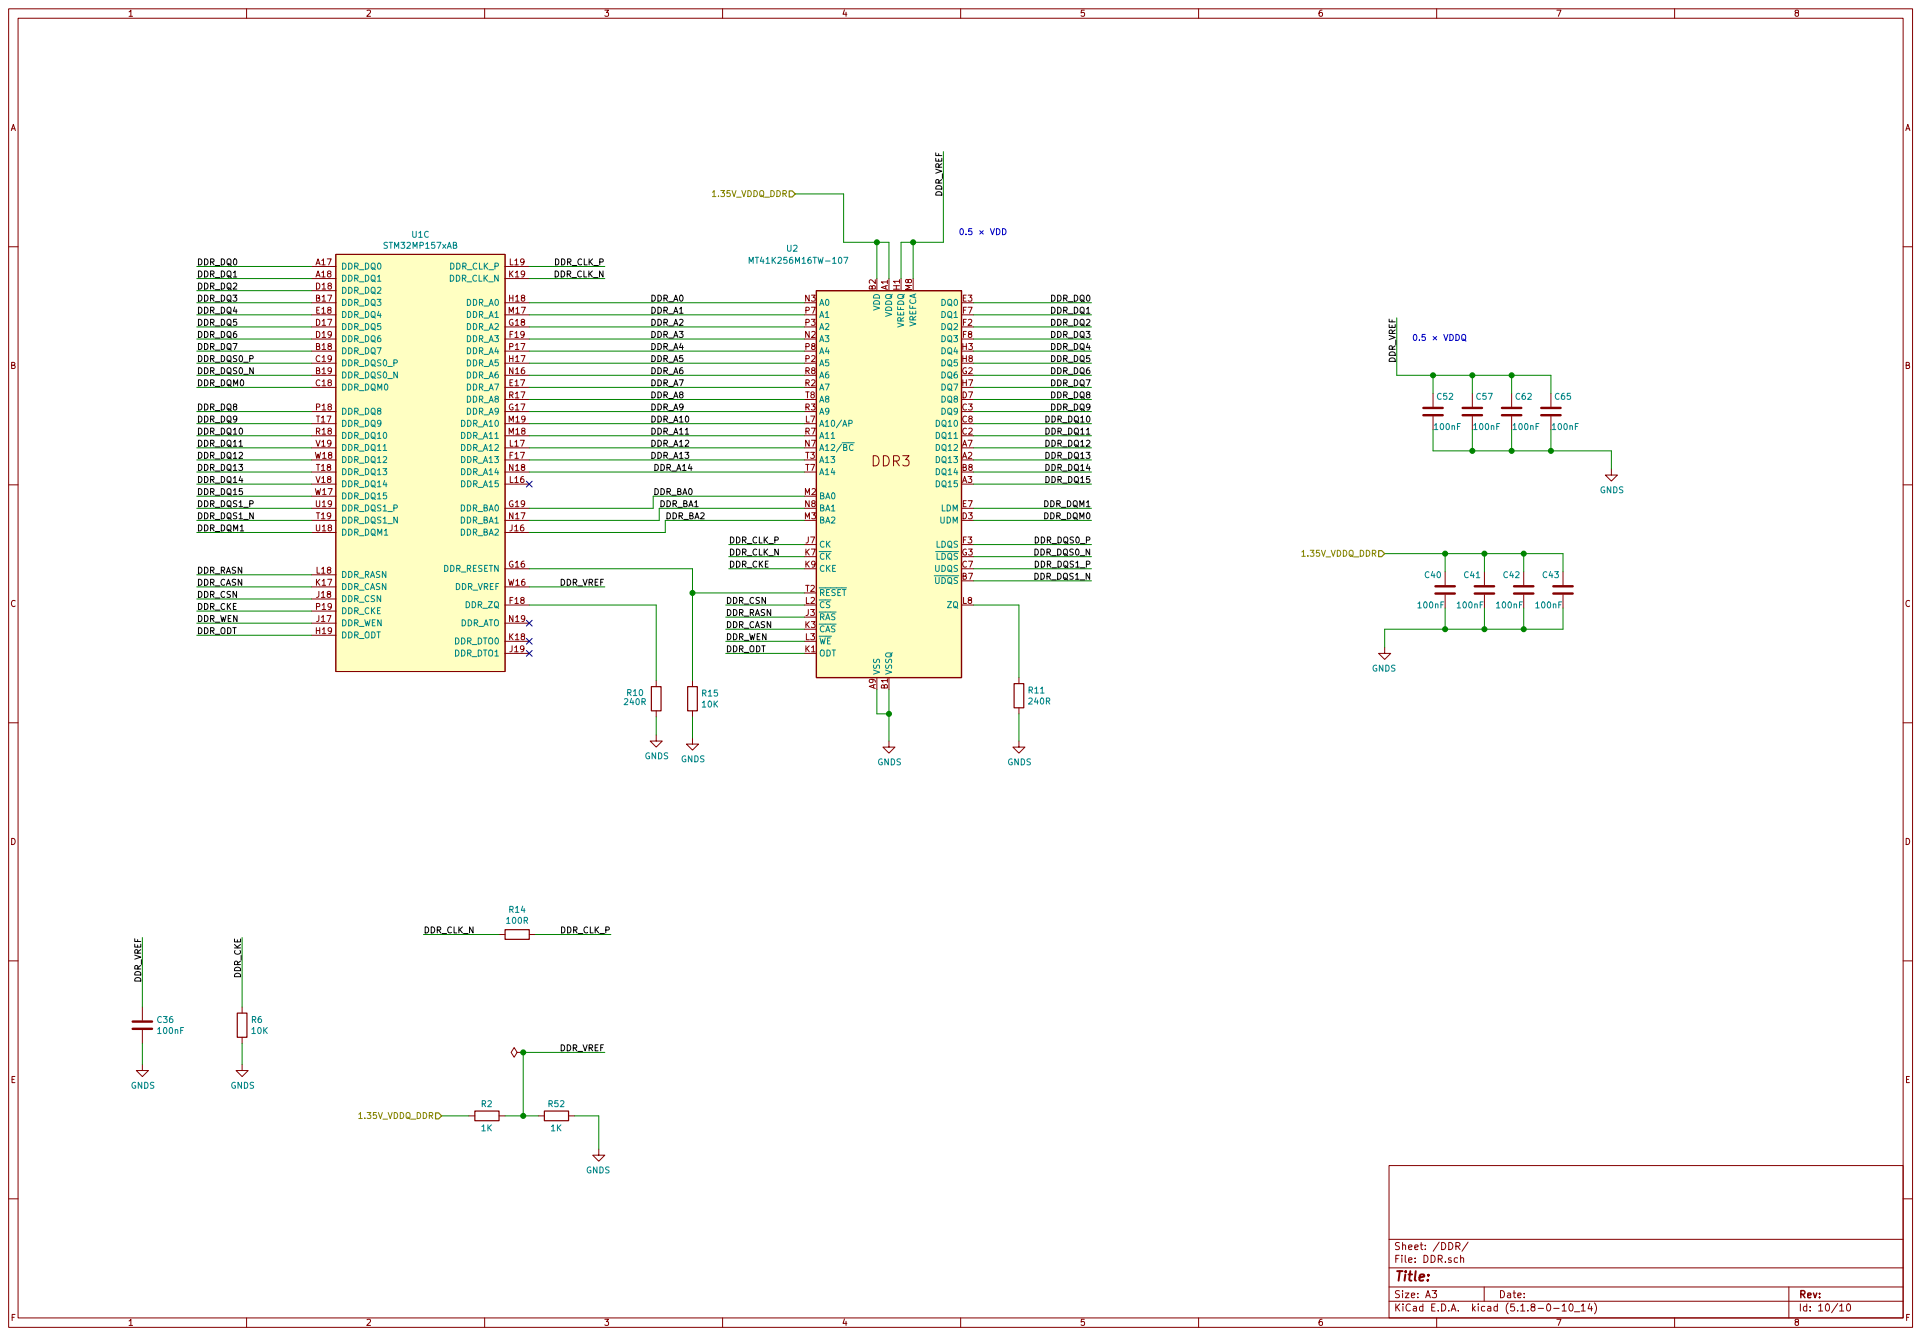
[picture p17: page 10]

Id: 10/10 Title: File: DDR.sch Sheet: /DDR/

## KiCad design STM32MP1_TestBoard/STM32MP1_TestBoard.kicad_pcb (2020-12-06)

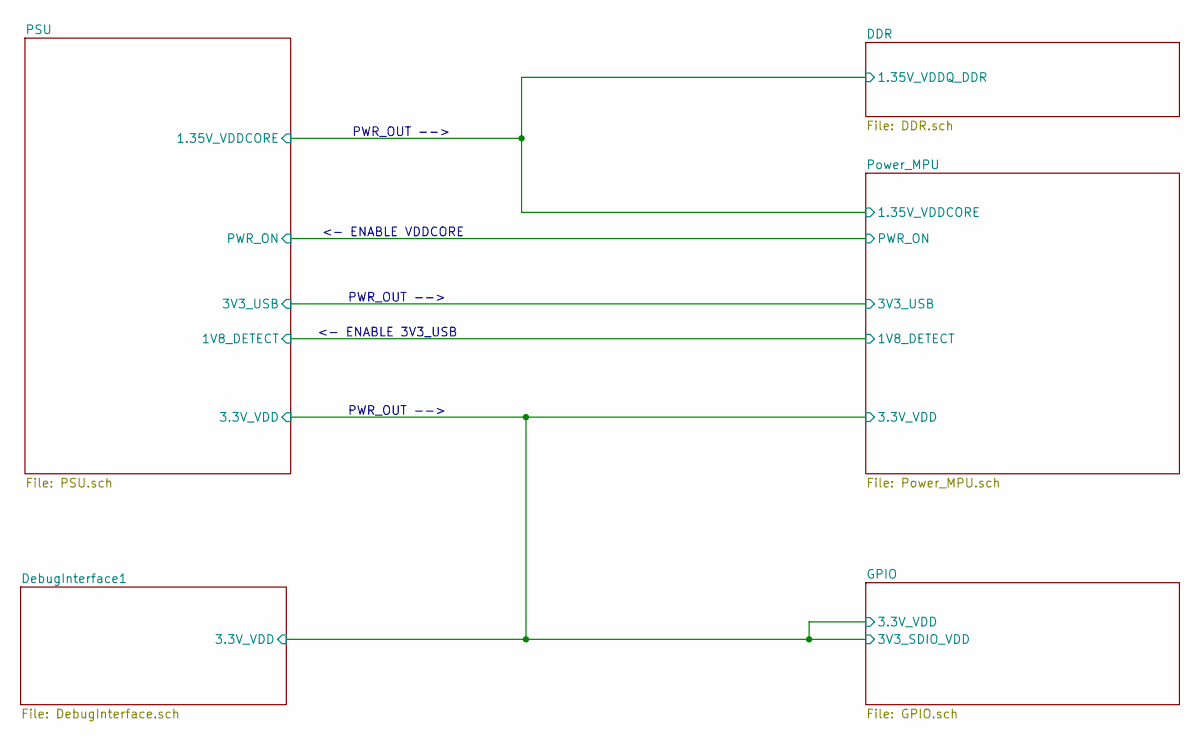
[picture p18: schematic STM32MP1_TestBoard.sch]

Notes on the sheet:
<- ENABLE VDDCORE
<- ENABLE 3V3_USB
PWR_OUT -->

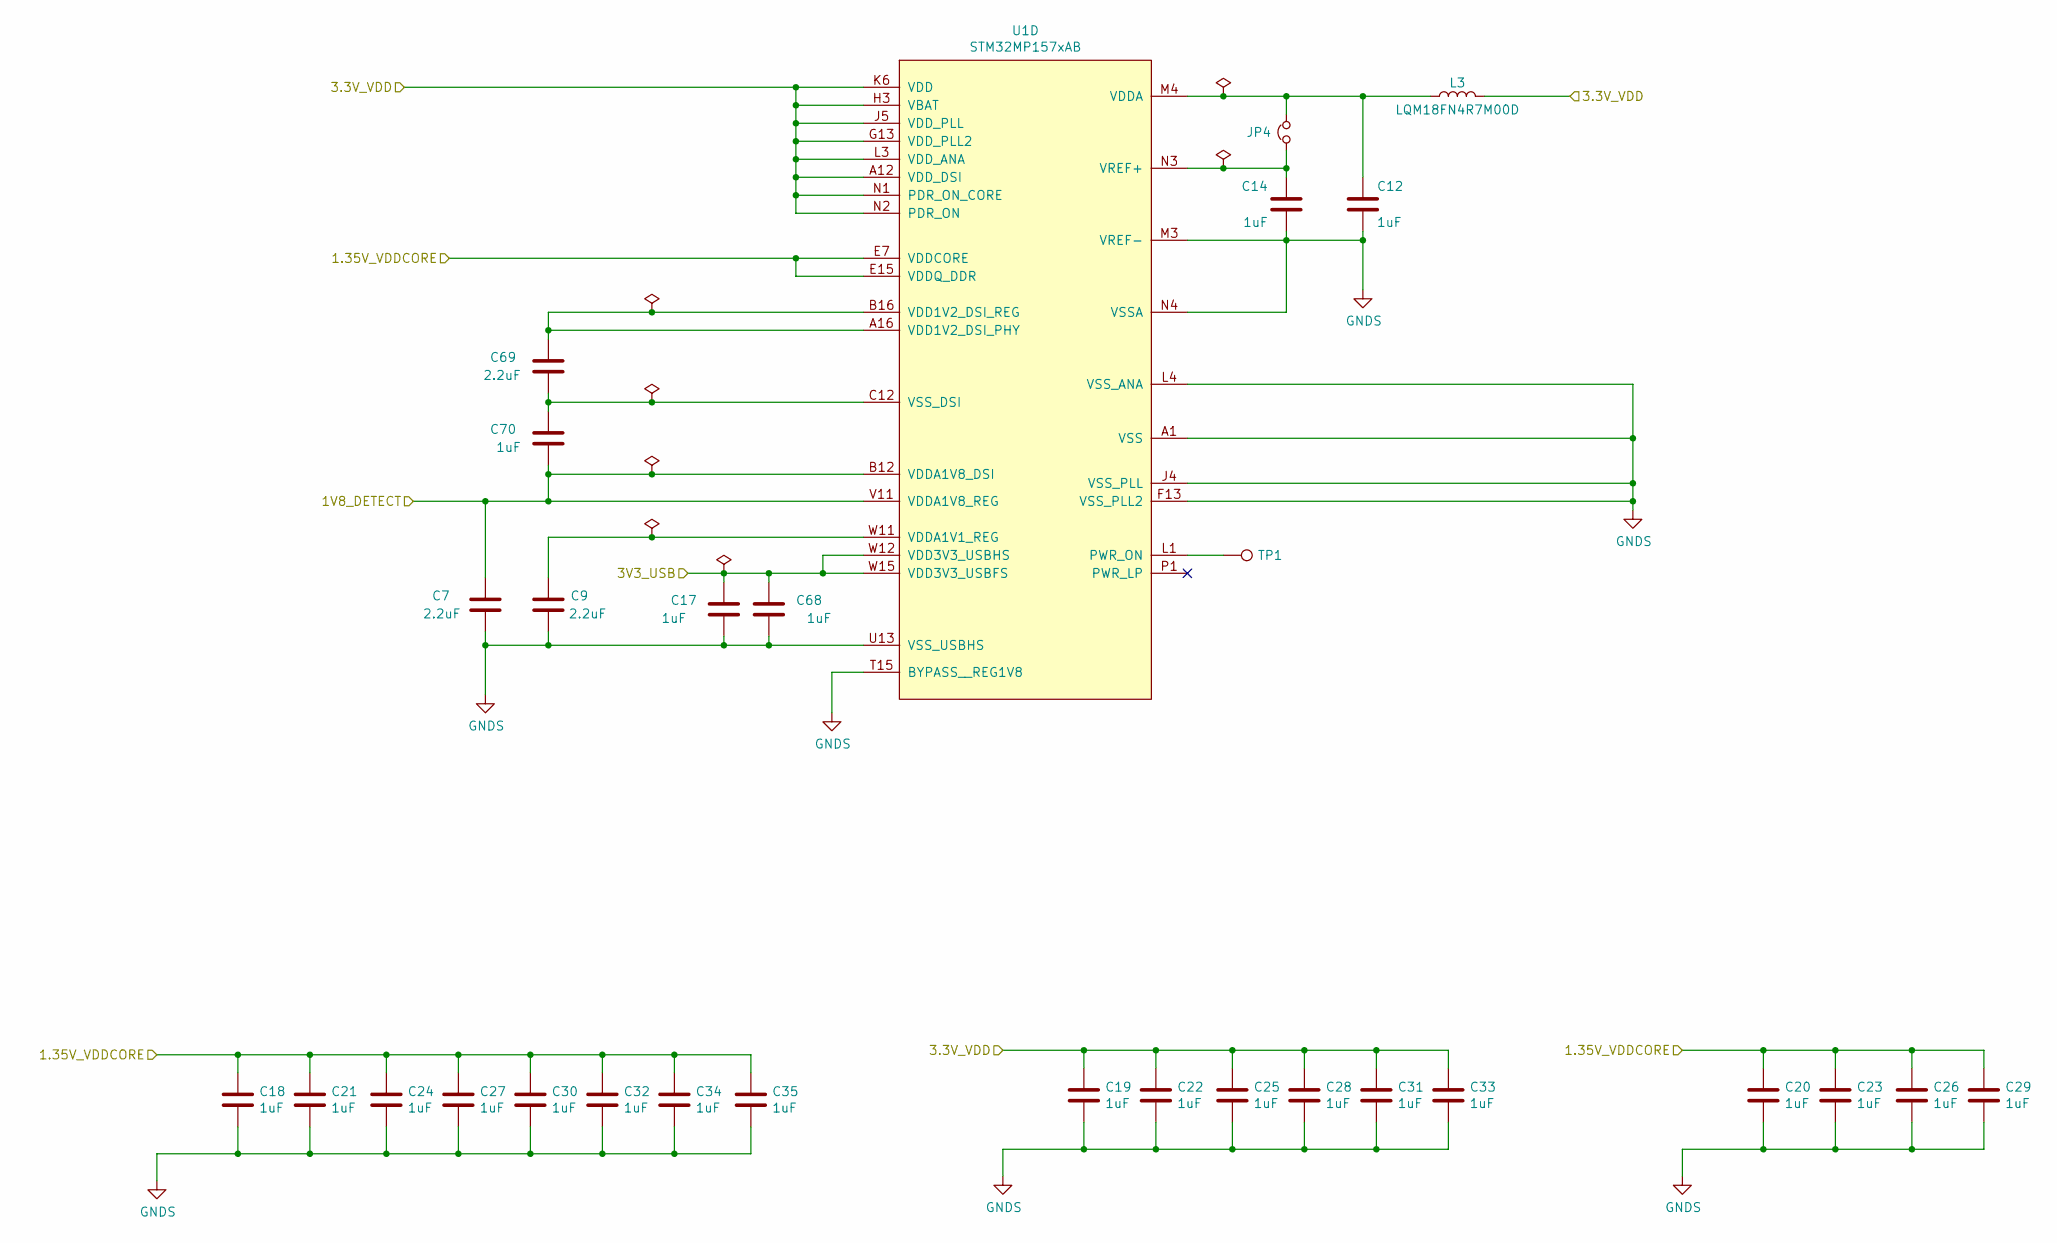
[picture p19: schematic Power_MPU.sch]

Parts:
C7, C9, C69: 2.2uF; C_0402_1005Metric_Pad0.74x0.62mm_HandSolder; PartNo LMK105BJ105KV-F
C12, C14, C17, C18, C19, C20, C21, C22, C23, C24, C25, C26, C27, C28, C29, C30, C31, C32, C33, C34, C35, C68, C70: 1uF; C_0402_1005Metric_Pad0.74x0.62mm_HandSolder; PartNo LMK105BJ105KV-F
JP4: Jumper_NC_Small; SolderJumper-2_P1.3mm_Bridged_Pad1.0x1.5mm
L3: LQM18FN4R7M00D; L_0201_0603Metric_Pad0.64x0.40mm_HandSolder
TP1: TestPoint; TestPoint_Pad_D1.0mm
U1: STM32MP157xAB; BGA-361_19x19_16.0x16.0mm

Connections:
/DebugInterface1/3.3V_VDD: C19.1, C22.1, C25.1, C28.1, C31.1, C33.1, L3.1, U1.A12 (VDD_DSI), U1.G13 (VDD_PLL2), U1.H3 (VBAT), U1.J5 (VDD_PLL), U1.K6 (VDD), U1.L3 (VDD_ANA), U1.L5 (VDD), U1.L7 (VDD), U1.M6 (VDD), U1.M8 (VDD), U1.N1 (PDR_ON_CORE), U1.N2 (PDR_ON), U1.N5 (VDD), U1.N7 (VDD), U1.N9 (VDD), U1.P6 (VDD), U1.P8 (VDD), U1.P10 (VDD), U1.R7 (VDD), U1.R9 (VDD), U1.R11 (VDD); also elsewhere on the board
/PSU/1.35V_VDDCORE: C18.1, C20.1, C21.1, C23.1, C24.1, C26.1, C27.1, C29.1, C30.1, C32.1, C34.1, C35.1, U1.E7 (VDDCORE), U1.E9 (VDDCORE), U1.E11 (VDDCORE), U1.E13 (VDDCORE), U1.E15 (VDDQ_DDR), U1.F4 (VDDCORE), U1.F6 (VDDCORE), U1.F8 (VDDCORE), U1.F10 (VDDCORE), U1.F12 (VDDCORE), U1.F14 (VDDQ_DDR), U1.G5 (VDDCORE), U1.G7 (VDDCORE), U1.G9 (VDDCORE), U1.G11 (VDDCORE), U1.G15 (VDDQ_DDR), U1.H4 (VDDCORE), U1.H6 (VDDCORE), U1.H8 (VDDCORE), U1.H10 (VDDCORE), U1.H12 (VDDCORE), U1.H14 (VDDQ_DDR), U1.J7 (VDDCORE), U1.J9 (VDDCORE), U1.J11 (VDDCORE), U1.J13 (VDDCORE), U1.J15 (VDDQ_DDR), U1.K8 (VDDCORE), U1.K10 (VDDCORE), U1.K12 (VDDCORE), U1.K14 (VDDQ_DDR), U1.L9 (VDDCORE), U1.L11 (VDDCORE), U1.L13 (VDDCORE), U1.L15 (VDDQ_DDR), U1.M10 (VDDCORE), U1.M12 (VDDCORE), U1.M14 (VDDQ_DDR), U1.N11 (VDDCORE), U1.N13 (VDDCORE), U1.N15 (VDDQ_DDR), U1.P12 (VDDCORE), U1.P14 (VDDQ_DDR), U1.R13 (VDDCORE), U1.R15 (VDDQ_DDR); also elsewhere on the board
/PSU/1V8_DETECT: C7.1, C70.1, U1.B12 (VDDA1V8_DSI), U1.V11 (VDDA1V8_REG); also elsewhere on the board
/PSU/3V3_USB: C17.1, C68.1, U1.W12 (VDD3V3_USBHS), U1.W15 (VDD3V3_USBFS); also elsewhere on the board
unnamed: C9.2, U1.W11 (VDDA1V1_REG)
unnamed: C12.2, JP4.2, L3.2, U1.M4 (VDDA)
unnamed: C14.2, JP4.1, U1.N3 (VREF+)
unnamed: C69.1, C70.2, U1.C12 (VSS_DSI), U1.C13 (VSS_DSI), U1.C14 (VSS_DSI), U1.C15 (VSS_DSI), U1.C16 (VSS_DSI)
unnamed: C69.2, U1.A16 (VDD1V2_DSI_PHY), U1.B16 (VDD1V2_DSI_REG)
unnamed: TP1.1, U1.L1 (PWR_ON)

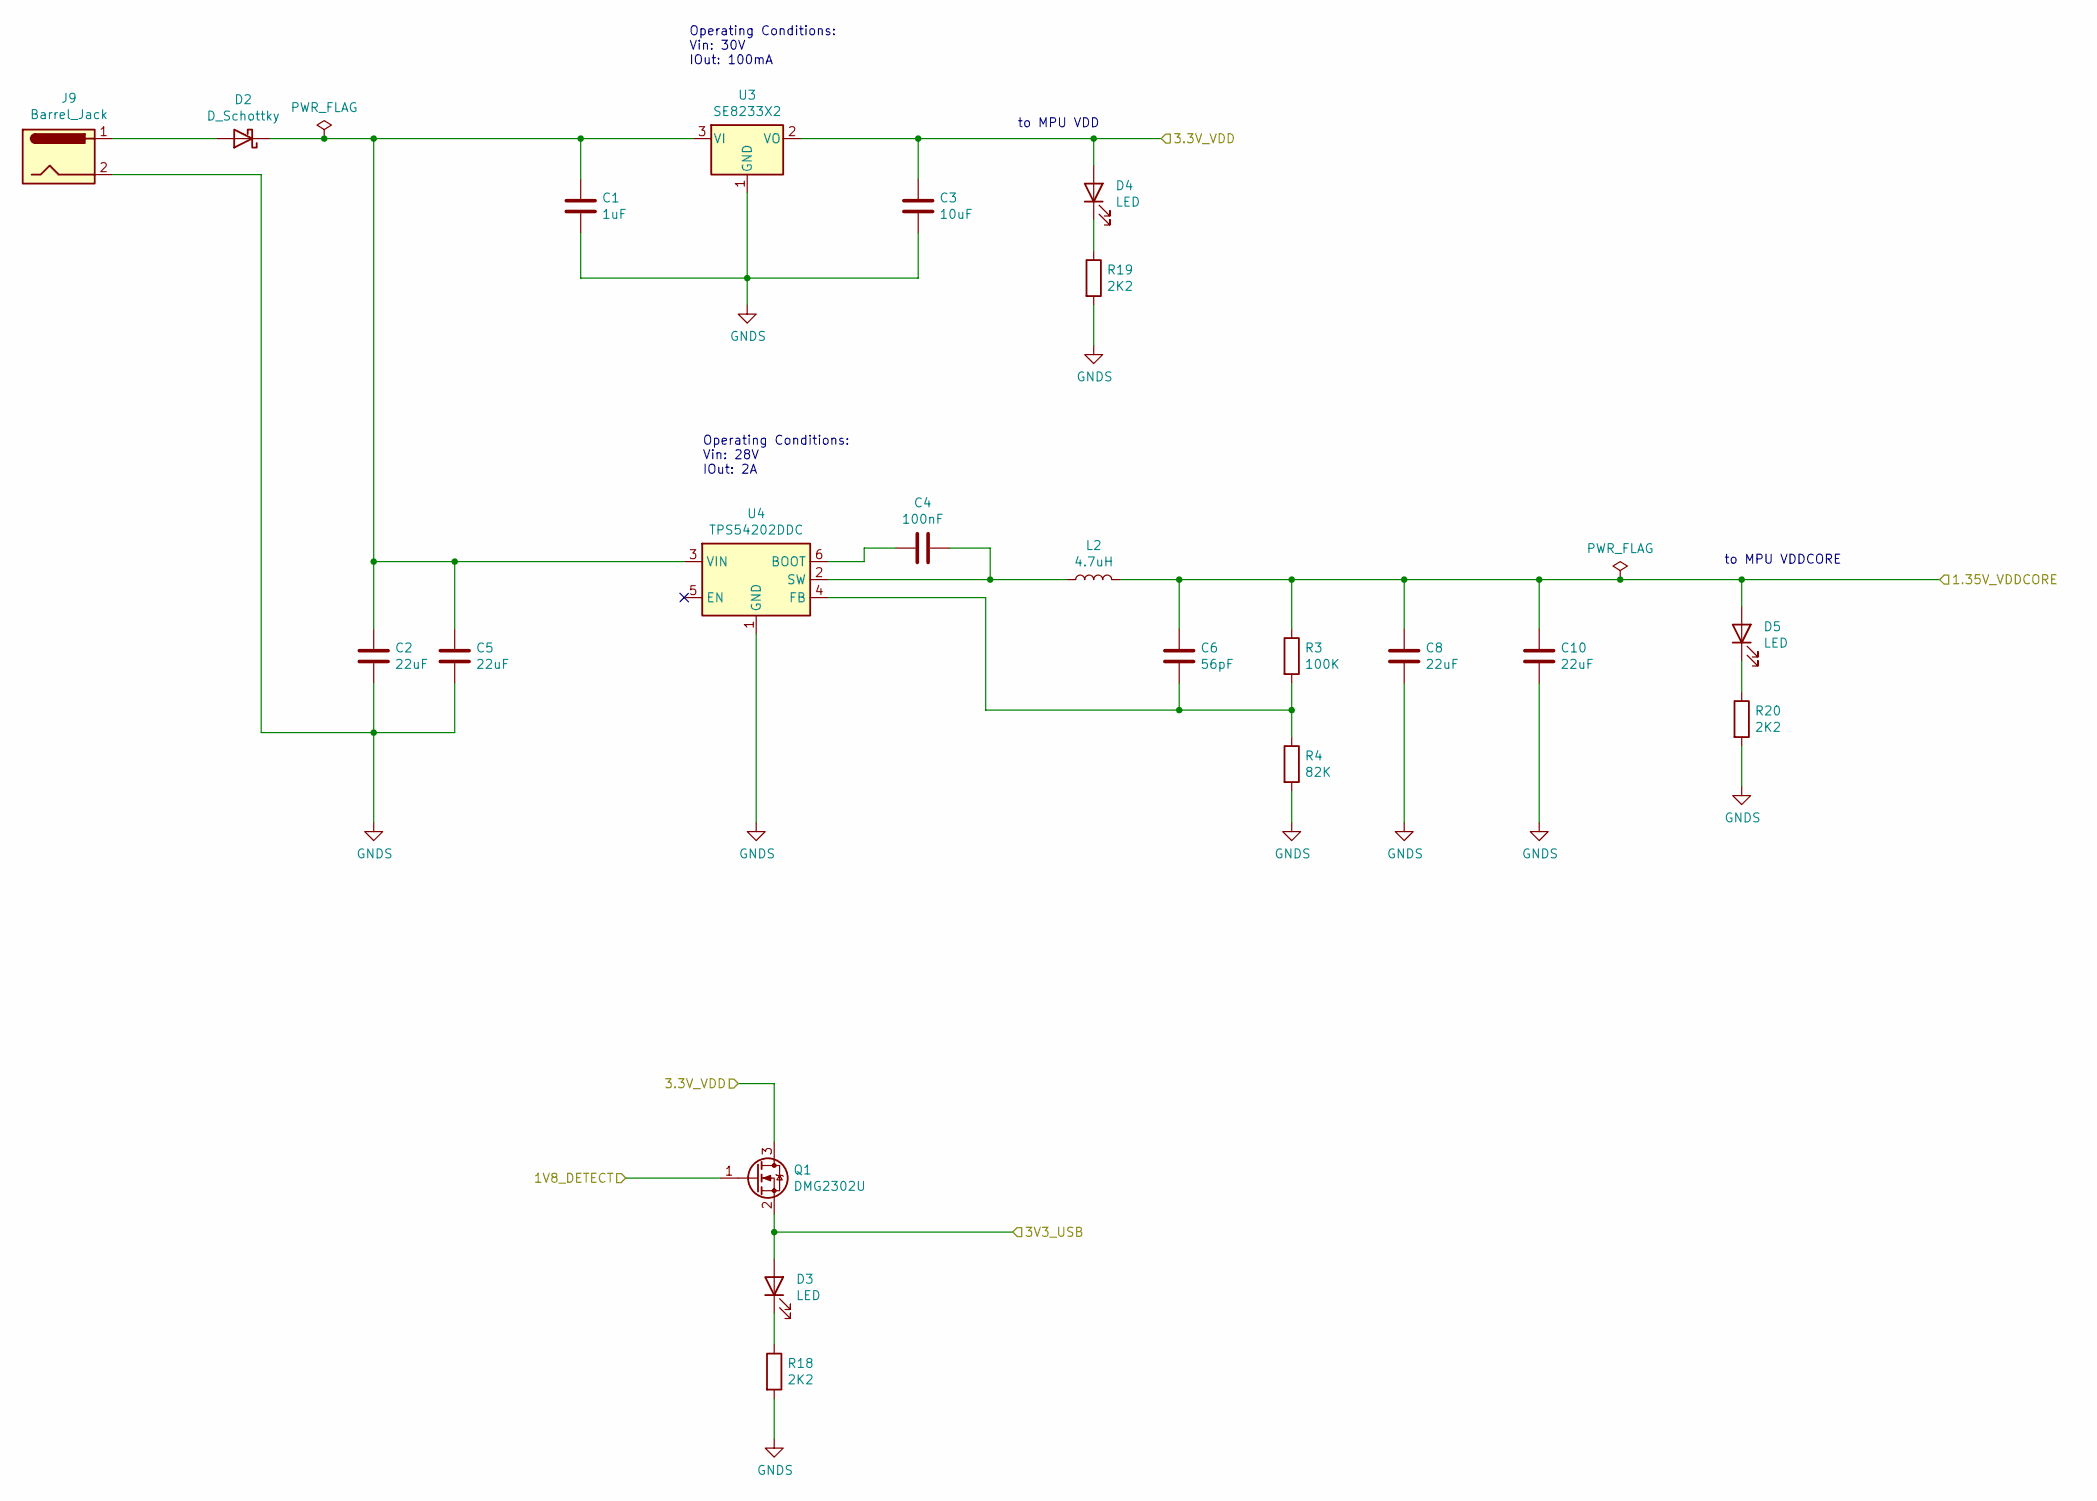
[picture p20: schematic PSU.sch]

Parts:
C1: 1uF; C_0402_1005Metric_Pad0.74x0.62mm_HandSolder
C2, C5, C8, C10: 22uF; C_1206_3216Metric_Pad1.33x1.80mm_HandSolder; PartNo C1206C226M8PACTU
C3: 10uF; C_0402_1005Metric_Pad0.74x0.62mm_HandSolder
C4: 100nF; C_0805_2012Metric_Pad1.18x1.45mm_HandSolder
C6: 56pF; C_0805_2012Metric_Pad1.18x1.45mm_HandSolder
D2: D_Schottky; D_SOD-123F
D3, D4, D5: LED; LED_0805_2012Metric_Pad1.15x1.40mm_HandSolder
J9: Barrel_Jack; BarrelJack_Horizontal
L2: 4.7uH; L_Bourns-SRN6028; PartNo SMNR6028-4R7MT
Q1: DMG2302U; SOT-23; PartNo DMG2302U
R3: 100K; R_0805_2012Metric_Pad1.20x1.40mm_HandSolder
R4: 82K; R_0805_2012Metric_Pad1.20x1.40mm_HandSolder
R18, R19, R20: 2K2; R_0402_1005Metric_Pad0.72x0.64mm_HandSolder
U3: SE8233X2; SOT-23
U4: TPS54202DDC; SOT-23-6; PartNo TPS54202DDCR

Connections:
/DebugInterface1/3.3V_VDD: C3.1, D4.2 (A), Q1.3 (D), U3.2 (VO); also elsewhere on the board
/PSU/1.35V_VDDCORE: C6.2, C8.1, C10.1, D5.2 (A), L2.2, R3.1; also elsewhere on the board
/PSU/1V8_DETECT: Q1.1 (G); also elsewhere on the board
/PSU/3V3_USB: D3.2 (A), Q1.2 (S); also elsewhere on the board
unnamed: C1.1, C2.1, C5.1, D2.1 (K), U3.3 (VI), U4.3 (VIN)
unnamed: C4.1, L2.1, U4.2 (SW)
unnamed: C4.2, U4.6 (BOOT)
unnamed: C6.1, R3.2, R4.1, U4.4 (FB)
unnamed: D2.2 (A), J9.1
unnamed: D3.1 (K), R18.1
unnamed: D4.1 (K), R19.1
unnamed: D5.1 (K), R20.1

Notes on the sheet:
to MPU VDD
to MPU VDDCORE
Operating Conditions: Vin: 30V IOut: 100mA
Operating Conditions: Vin: 28V IOut: 2A

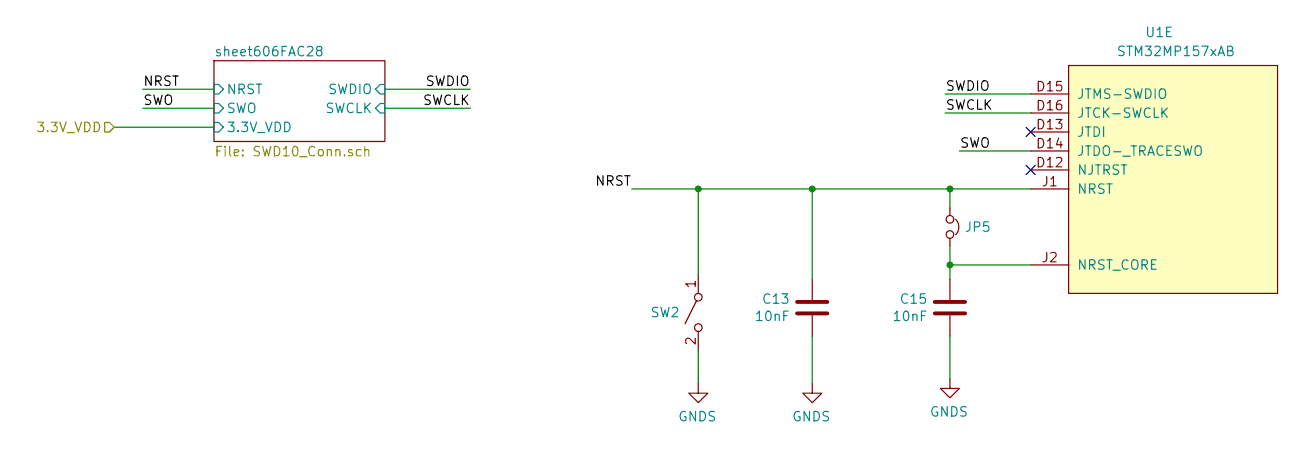
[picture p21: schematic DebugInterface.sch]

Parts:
C13, C15: 10nF; C_0402_1005Metric_Pad0.74x0.62mm_HandSolder
JP5: Jumper_NC_Small; SolderJumper-2_P1.3mm_Bridged_RoundedPad1.0x1.5mm
SW2: SW_SPST; Panasonic_EVQPUK_EVQPUB
U1: STM32MP157xAB; BGA-361_19x19_16.0x16.0mm

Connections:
/DebugInterface1/NRST: C13.1, JP5.1, SW2.1 (A), U1.J1 (NRST); also elsewhere on the board
/DebugInterface1/SWCLK: U1.D16 (JTCK-SWCLK); also elsewhere on the board
/DebugInterface1/SWDIO: U1.D15 (JTMS-SWDIO); also elsewhere on the board
/DebugInterface1/SWO: U1.D14 (JTDO-_TRACESWO); also elsewhere on the board
unnamed: C15.1, JP5.2, U1.J2 (NRST_CORE)

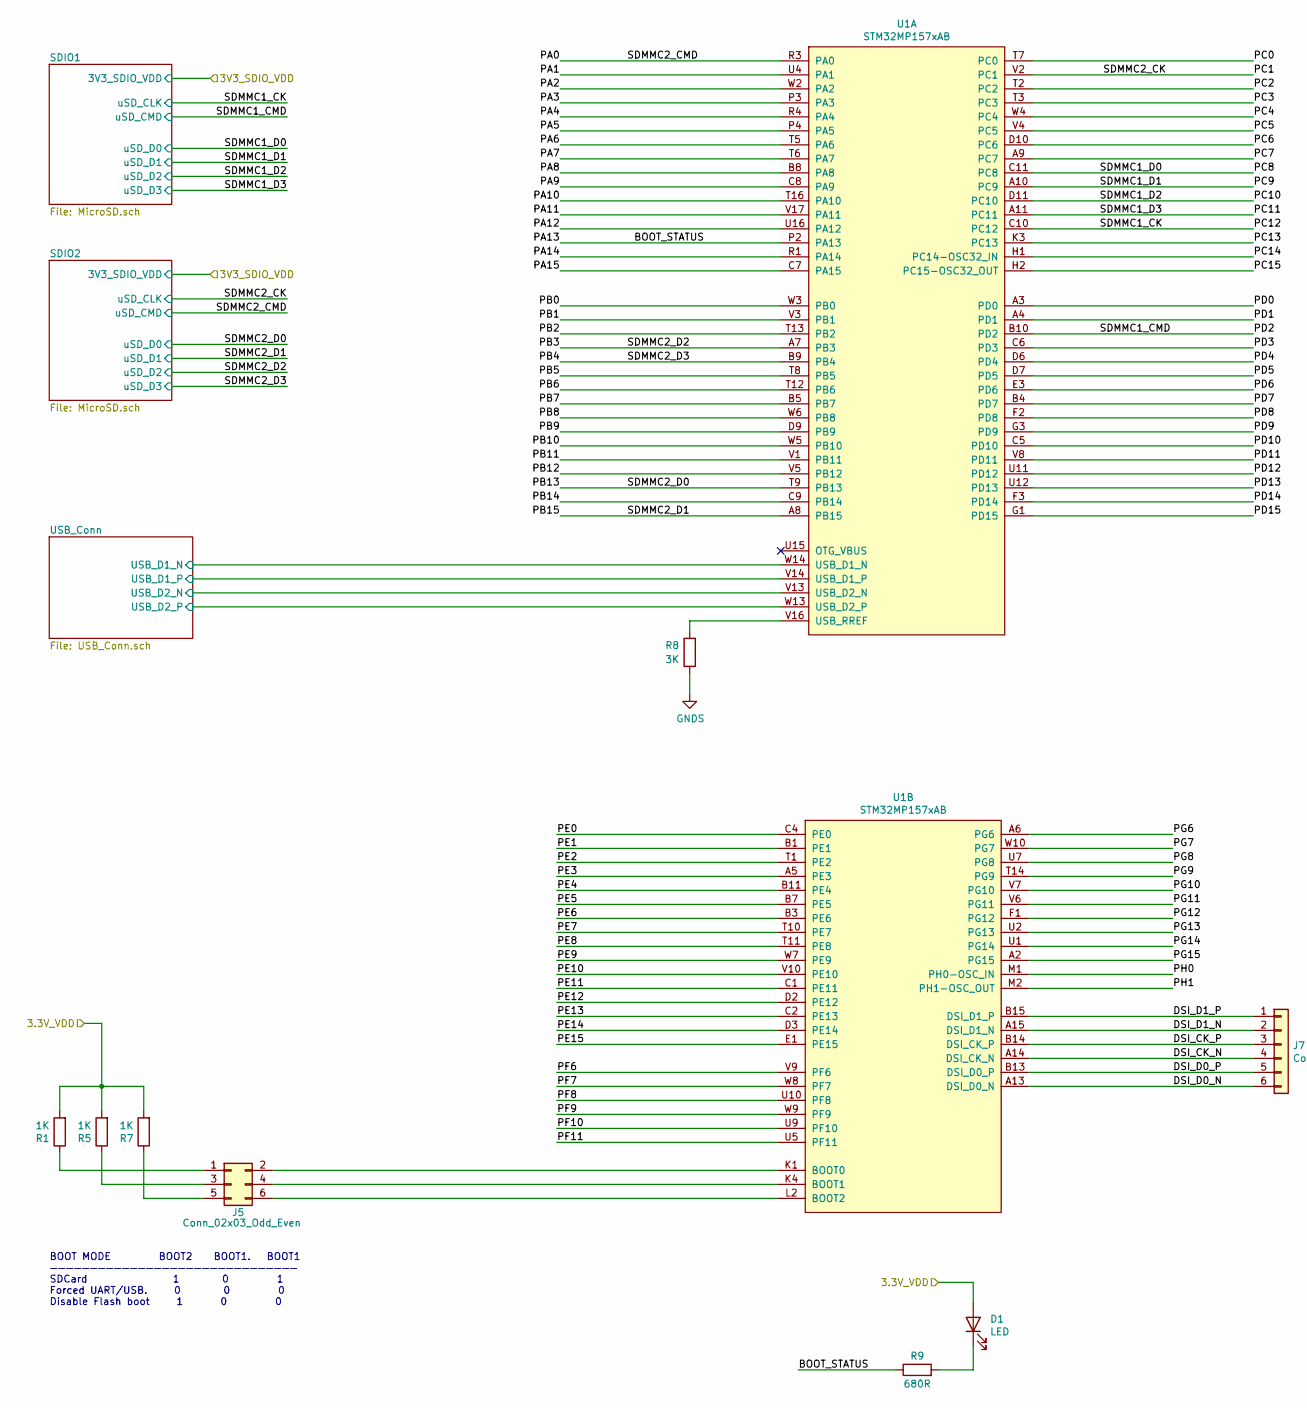
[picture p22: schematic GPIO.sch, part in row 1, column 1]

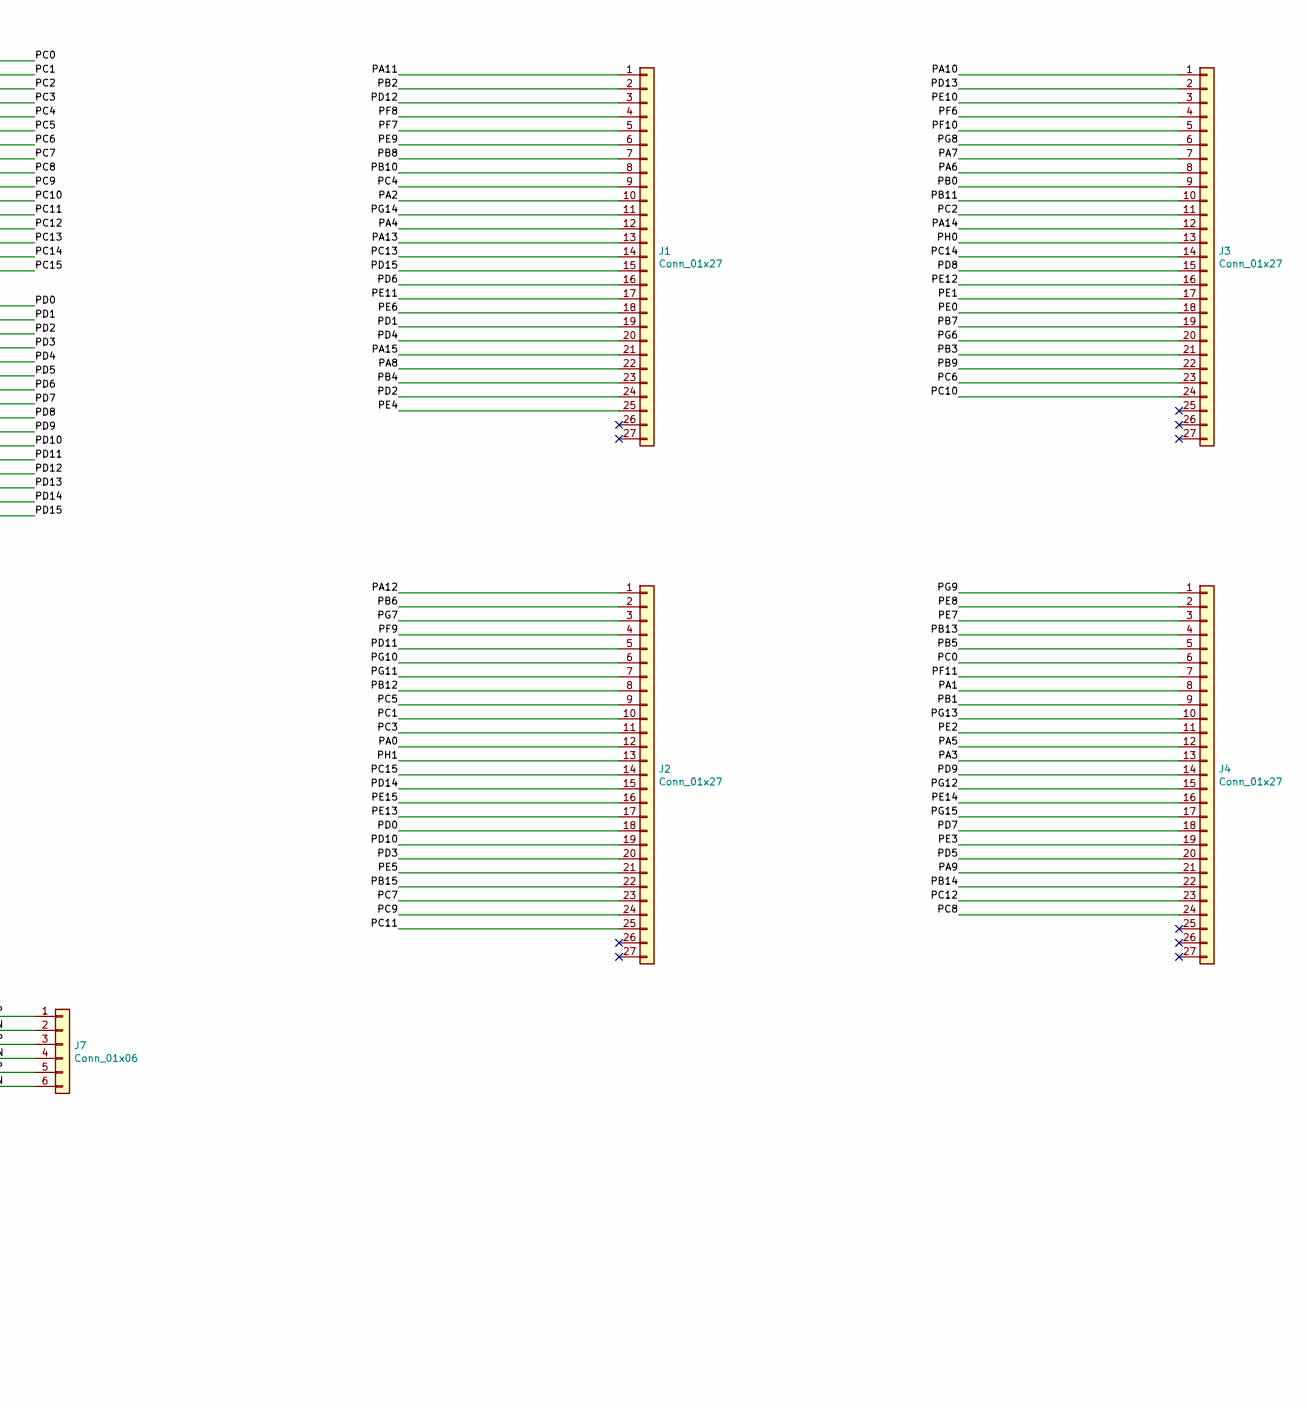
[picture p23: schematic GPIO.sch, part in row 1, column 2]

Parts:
D1: LED; LED_0805_2012Metric_Pad1.15x1.40mm_HandSolder
J1, J2, J3, J4: Conn_01x27; PinHeader_1x27_P2.54mm_Vertical
J5: Conn_02x03_Odd_Even; PinHeader_2x03_P2.54mm_Vertical
J7: Conn_01x06; PinHeader_1x06_P2.54mm_Vertical
R1, R5, R7: 1K; R_0402_1005Metric_Pad0.72x0.64mm_HandSolder
R8: 3K; R_0402_1005Metric_Pad0.72x0.64mm_HandSolder
R9: 680R; R_0402_1005Metric_Pad0.72x0.64mm_HandSolder
U1: STM32MP157xAB; BGA-361_19x19_16.0x16.0mm

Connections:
/DebugInterface1/3.3V_VDD: D1.2 (A), R1.2, R5.2, R7.2; also elsewhere on the board
/GPIO/BOOT_STATUS: J1.13, R9.1, U1.P2 (PA13)
/GPIO/DSI_CK_N: J7.4, U1.A14 (DSI_CK_N)
/GPIO/DSI_CK_P: J7.3, U1.B14 (DSI_CK_P)
/GPIO/DSI_D0_N: J7.6, U1.A13 (DSI_D0_N)
/GPIO/DSI_D0_P: J7.5, U1.B13 (DSI_D0_P)
/GPIO/DSI_D1_N: J7.2, U1.A15 (DSI_D1_N)
/GPIO/DSI_D1_P: J7.1, U1.B15 (DSI_D1_P)
/GPIO/PA0: J2.12, U1.R3 (PA0); also elsewhere on the board
/GPIO/PA1: J4.8, U1.U4 (PA1)
/GPIO/PA2: J1.10, U1.W2 (PA2)
/GPIO/PA3: J4.13, U1.P3 (PA3)
/GPIO/PA4: J1.12, U1.R4 (PA4)
/GPIO/PA5: J4.12, U1.P4 (PA5)
/GPIO/PA6: J3.8, U1.T5 (PA6)
/GPIO/PA7: J3.7, U1.T6 (PA7)
/GPIO/PA8: J1.22, U1.B8 (PA8)
/GPIO/PA9: J4.21, U1.C8 (PA9)
/GPIO/PA10: J3.1, U1.T16 (PA10)
/GPIO/PA11: J1.1, U1.V17 (PA11)
/GPIO/PA12: J2.1, U1.U16 (PA12)
/GPIO/PA14: J3.12, U1.R1 (PA14)
/GPIO/PA15: J1.21, U1.C7 (PA15)
/GPIO/PB0: J3.9, U1.W3 (PB0)
/GPIO/PB1: J4.9, U1.V3 (PB1)
/GPIO/PB2: J1.2, U1.T13 (PB2)
/GPIO/PB5: J4.5, U1.T8 (PB5)
/GPIO/PB6: J2.2, U1.T12 (PB6)
/GPIO/PB7: J3.19, U1.B5 (PB7)
/GPIO/PB8: J1.7, U1.W6 (PB8)
/GPIO/PB9: J3.22, U1.D9 (PB9)
/GPIO/PB10: J1.8, U1.W5 (PB10)
/GPIO/PB11: J3.10, U1.V1 (PB11)
/GPIO/PB12: J2.8, U1.V5 (PB12)
/GPIO/PB13: J4.4, U1.T9 (PB13); also elsewhere on the board
/GPIO/PB14: J4.22, U1.C9 (PB14)
/GPIO/PB15: J2.22, U1.A8 (PB15); also elsewhere on the board
/GPIO/PC0: J4.6, U1.T7 (PC0)
/GPIO/PC2: J3.11, U1.T2 (PC2)
/GPIO/PC3: J2.11, U1.T3 (PC3)
/GPIO/PC5: J2.9, U1.V4 (PC5)
/GPIO/PC6: J3.23, U1.D10 (PC6)
/GPIO/PC7: J2.23, U1.A9 (PC7)
/GPIO/PC12: J4.23, U1.C10 (PC12); also elsewhere on the board
/GPIO/PC13: J1.14, U1.K3 (PC13)
/GPIO/PC14: J3.14, U1.H1 (PC14-OSC32_IN)
/GPIO/PC15: J2.14, U1.H2 (PC15-OSC32_OUT)
/GPIO/PD0: J2.18, U1.A3 (PD0)
/GPIO/PD1: J1.19, U1.A4 (PD1)
/GPIO/PD3: J2.20, U1.C6 (PD3)
/GPIO/PD4: J1.20, U1.D6 (PD4)
/GPIO/PD5: J4.20, U1.D7 (PD5)
/GPIO/PD6: J1.16, U1.E3 (PD6)
/GPIO/PD7: J4.18, U1.B4 (PD7)
/GPIO/PD8: J3.15, U1.F2 (PD8)
/GPIO/PD9: J4.14, U1.G3 (PD9)
/GPIO/PD10: J2.19, U1.C5 (PD10)
/GPIO/PD11: J2.5, U1.V8 (PD11)
/GPIO/PD13: J3.2, U1.U12 (PD13)
/GPIO/PD14: J2.15, U1.F3 (PD14)
/GPIO/PD15: J1.15, U1.G1 (PD15)
/GPIO/PE0: J3.18, U1.C4 (PE0)
/GPIO/PE1: J3.17, U1.B1 (PE1)
/GPIO/PE2: J4.11, U1.T1 (PE2)
/GPIO/PE3: J4.19, U1.A5 (PE3)
/GPIO/PE4: J1.25, U1.B11 (PE4)
/GPIO/PE5: J2.21, U1.B7 (PE5)
/GPIO/PE6: J1.18, U1.B3 (PE6)
/GPIO/PE7: J4.3, U1.T10 (PE7)
/GPIO/PE8: J4.2, U1.T11 (PE8)
/GPIO/PE9: J1.6, U1.W7 (PE9)
/GPIO/PE10: J3.3, U1.V10 (PE10)
/GPIO/PE11: J1.17, U1.C1 (PE11)
/GPIO/PE12: J3.16, U1.D2 (PE12)
/GPIO/PE13: J2.17, U1.C2 (PE13)
/GPIO/PE14: J4.16, U1.D3 (PE14)
/GPIO/PE15: J2.16, U1.E1 (PE15)
/GPIO/PF6: J3.4, U1.V9 (PF6)
/GPIO/PF8: J1.4, U1.U10 (PF8)
/GPIO/PF9: J2.4, U1.W9 (PF9)
/GPIO/PF10: J3.5, U1.U9 (PF10)
/GPIO/PF11: J4.7, U1.U5 (PF11)
/GPIO/PG6: J3.20, U1.A6 (PG6)
/GPIO/PG7: J2.3, U1.W10 (PG7)
/GPIO/PG8: J3.6, U1.U7 (PG8)
/GPIO/PG9: J4.1, U1.T14 (PG9)
/GPIO/PG10: J2.6, U1.V7 (PG10)
/GPIO/PG11: J2.7, U1.V6 (PG11)
/GPIO/PG12: J4.15, U1.F1 (PG12)
/GPIO/PG13: J4.10, U1.U2 (PG13)
/GPIO/PG14: J1.11, U1.U1 (PG14)
/GPIO/PG15: J4.17, U1.A2 (PG15)
/GPIO/PH0: J3.13, U1.M1 (PH0-OSC_IN)
/GPIO/PH1: J2.13, U1.M2 (PH1-OSC_OUT)
/GPIO/USB_Conn/USB_D1_N: U1.W14 (USB_D1_N); also elsewhere on the board
/GPIO/USB_Conn/USB_D1_P: U1.V14 (USB_D1_P); also elsewhere on the board
/GPIO/USB_Conn/USB_D2_N: U1.V13 (USB_D2_N); also elsewhere on the board
/GPIO/USB_Conn/USB_D2_P: U1.W13 (USB_D2_P); also elsewhere on the board
unnamed: D1.1 (K), R9.2
unnamed: J5.1, R1.1
unnamed: J5.2, U1.K1 (BOOT0)
unnamed: J5.3, R5.1
unnamed: J5.4, U1.K4 (BOOT1)
unnamed: J5.5, R7.1
unnamed: J5.6, U1.L2 (BOOT2)
unnamed: R8.2, U1.V16 (USB_RREF)

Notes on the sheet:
BOOT MODE BOOT2 BOOT1. BOOT1 ——————————————————————————————— SDCard 1 0 1 Forced UART/USB. 0 0 0 Disable Flash boot 1 0 0

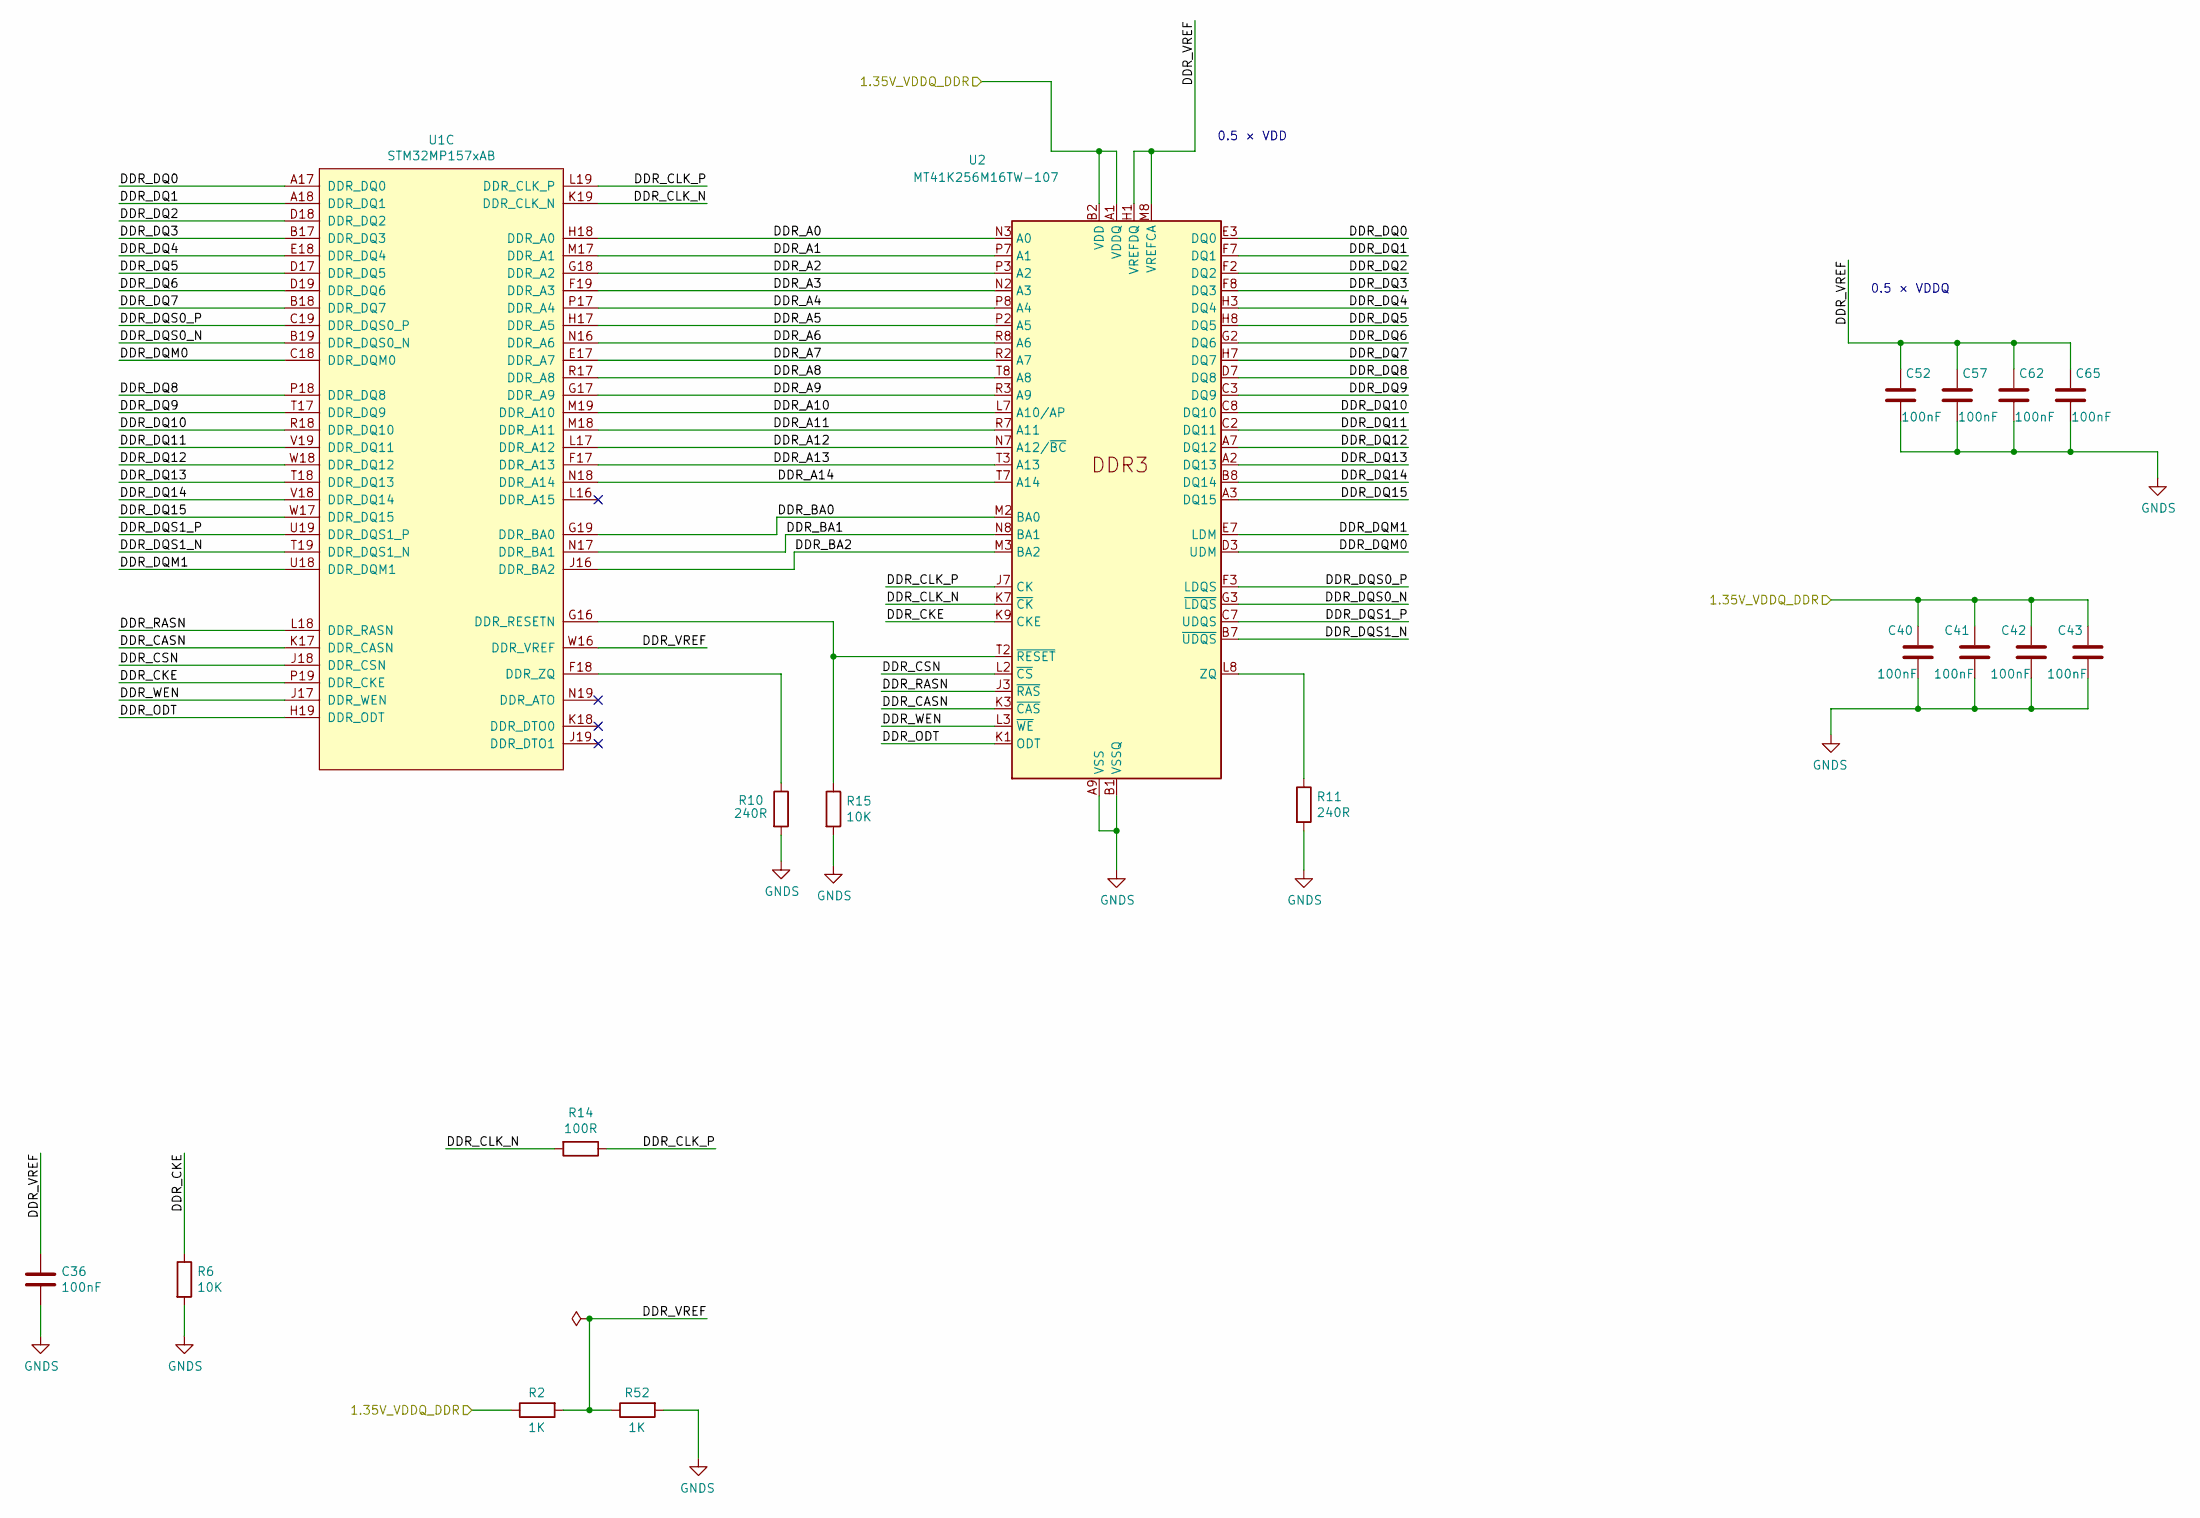
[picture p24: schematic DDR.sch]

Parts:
C36, C40, C41, C42, C43, C52, C57, C62, C65: 100nF; C_0402_1005Metric_Pad0.74x0.62mm_HandSolder
R2, R52: 1K; R_0402_1005Metric_Pad0.72x0.64mm_HandSolder
R6, R15: 10K; R_0402_1005Metric_Pad0.72x0.64mm_HandSolder
R10, R11: 240R; R_0402_1005Metric_Pad0.72x0.64mm_HandSolder
R14: 100R; R_0402_1005Metric_Pad0.72x0.64mm_HandSolder
U1: STM32MP157xAB; BGA-361_19x19_16.0x16.0mm
U2: MT41K256M16TW-107; BGA-96_9.0x13.0mm_Layout2x3x16_P0.8mm; PartNo MT41K256M16TW-107

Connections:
/DDR/DDR_A0: U1.H18 (DDR_A0), U2.N3 (A0)
/DDR/DDR_A1: U1.M17 (DDR_A1), U2.P7 (A1)
/DDR/DDR_A2: U1.G18 (DDR_A2), U2.P3 (A2)
/DDR/DDR_A3: U1.F19 (DDR_A3), U2.N2 (A3)
/DDR/DDR_A4: U1.P17 (DDR_A4), U2.P8 (A4)
/DDR/DDR_A5: U1.H17 (DDR_A5), U2.P2 (A5)
/DDR/DDR_A6: U1.N16 (DDR_A6), U2.R8 (A6)
/DDR/DDR_A7: U1.E17 (DDR_A7), U2.R2 (A7)
/DDR/DDR_A8: U1.R17 (DDR_A8), U2.T8 (A8)
/DDR/DDR_A9: U1.G17 (DDR_A9), U2.R3 (A9)
/DDR/DDR_A10: U1.M19 (DDR_A10), U2.L7 (A10/AP)
/DDR/DDR_A11: U1.M18 (DDR_A11), U2.R7 (A11)
/DDR/DDR_A12: U1.L17 (DDR_A12), U2.N7 (A12/~BC)
/DDR/DDR_A13: U1.F17 (DDR_A13), U2.T3 (A13)
/DDR/DDR_A14: U1.N18 (DDR_A14), U2.T7 (A14)
/DDR/DDR_BA0: U1.G19 (DDR_BA0), U2.M2 (BA0)
/DDR/DDR_BA1: U1.N17 (DDR_BA1), U2.N8 (BA1)
/DDR/DDR_BA2: U1.J16 (DDR_BA2), U2.M3 (BA2)
/DDR/DDR_CASN: U1.K17 (DDR_CASN), U2.K3 (~CAS)
/DDR/DDR_CKE: R6.1, U1.P19 (DDR_CKE), U2.K9 (CKE)
/DDR/DDR_CLK_N: R14.2, U1.K19 (DDR_CLK_N), U2.K7 (~CK)
/DDR/DDR_CLK_P: R14.1, U1.L19 (DDR_CLK_P), U2.J7 (CK)
/DDR/DDR_CSN: U1.J18 (DDR_CSN), U2.L2 (~CS)
/DDR/DDR_DQ0: U1.A17 (DDR_DQ0), U2.E3 (DQ0)
/DDR/DDR_DQ1: U1.A18 (DDR_DQ1), U2.F7 (DQ1)
/DDR/DDR_DQ2: U1.D18 (DDR_DQ2), U2.F2 (DQ2)
/DDR/DDR_DQ3: U1.B17 (DDR_DQ3), U2.F8 (DQ3)
/DDR/DDR_DQ4: U1.E18 (DDR_DQ4), U2.H3 (DQ4)
/DDR/DDR_DQ5: U1.D17 (DDR_DQ5), U2.H8 (DQ5)
/DDR/DDR_DQ6: U1.D19 (DDR_DQ6), U2.G2 (DQ6)
/DDR/DDR_DQ7: U1.B18 (DDR_DQ7), U2.H7 (DQ7)
/DDR/DDR_DQ8: U1.P18 (DDR_DQ8), U2.D7 (DQ8)
/DDR/DDR_DQ9: U1.T17 (DDR_DQ9), U2.C3 (DQ9)
/DDR/DDR_DQ10: U1.R18 (DDR_DQ10), U2.C8 (DQ10)
/DDR/DDR_DQ11: U1.V19 (DDR_DQ11), U2.C2 (DQ11)
/DDR/DDR_DQ12: U1.W18 (DDR_DQ12), U2.A7 (DQ12)
/DDR/DDR_DQ13: U1.T18 (DDR_DQ13), U2.A2 (DQ13)
/DDR/DDR_DQ14: U1.V18 (DDR_DQ14), U2.B8 (DQ14)
/DDR/DDR_DQ15: U1.W17 (DDR_DQ15), U2.A3 (DQ15)
/DDR/DDR_DQM0: U1.C18 (DDR_DQM0), U2.D3 (UDM)
/DDR/DDR_DQM1: U1.U18 (DDR_DQM1), U2.E7 (LDM)
/DDR/DDR_DQS0_N: U1.B19 (DDR_DQS0_N), U2.G3 (~LDQS)
/DDR/DDR_DQS0_P: U1.C19 (DDR_DQS0_P), U2.F3 (LDQS)
/DDR/DDR_DQS1_N: U1.T19 (DDR_DQS1_N), U2.B7 (~UDQS)
/DDR/DDR_DQS1_P: U1.U19 (DDR_DQS1_P), U2.C7 (UDQS)
/DDR/DDR_ODT: U1.H19 (DDR_ODT), U2.K1 (ODT)
/DDR/DDR_RASN: U1.L18 (DDR_RASN), U2.J3 (~RAS)
/DDR/DDR_VREF: C36.1, C52.1, C57.1, C62.1, C65.1, R2.2, R52.1, U1.W16 (DDR_VREF), U2.H1 (VREFDQ), U2.M8 (VREFCA)
/DDR/DDR_WEN: U1.J17 (DDR_WEN), U2.L3 (~WE)
/PSU/1.35V_VDDCORE: C40.1, C41.1, C42.1, C43.1, R2.1, U2.A1 (VDDQ), U2.A8 (VDDQ), U2.B2 (VDD), U2.C1 (VDDQ), U2.C9 (VDDQ), U2.D2 (VDDQ), U2.D9 (VDD), U2.E9 (VDDQ), U2.F1 (VDDQ), U2.G7 (VDD), U2.H2 (VDDQ), U2.H9 (VDDQ), U2.K2 (VDD), U2.K8 (VDD), U2.N1 (VDD), U2.N9 (VDD), U2.R1 (VDD), U2.R9 (VDD); also elsewhere on the board
unnamed: R10.1, U1.F18 (DDR_ZQ)
unnamed: R11.1, U2.L8 (ZQ)
unnamed: R15.1, U1.G16 (DDR_RESETN), U2.T2 (~RESET)

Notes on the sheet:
0.5 × VDDQ
0.5 × VDD

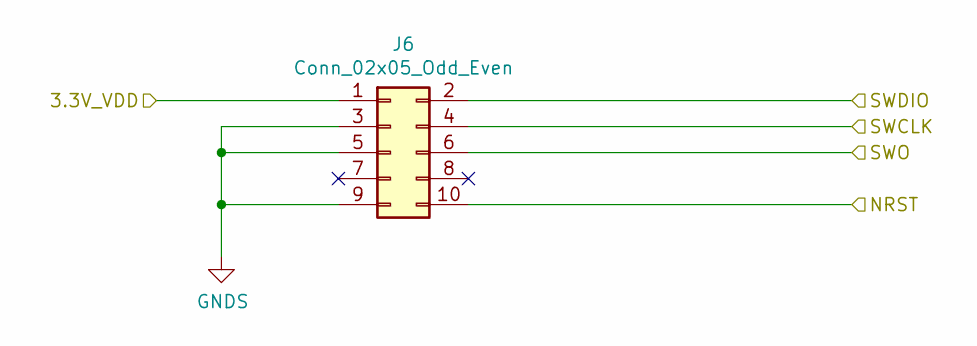
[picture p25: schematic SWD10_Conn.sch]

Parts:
J1: Conn_02x05_Odd_Even; PinHeader_2x05_P1.27mm_Vertical_SMD; PartNo 20021121-00010C4LF

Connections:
/GPIO/PA2: J1.10; also elsewhere on the board
/GPIO/PA11: J1.1; also elsewhere on the board
/GPIO/PB2: J1.2; also elsewhere on the board
/GPIO/PB8: J1.7; also elsewhere on the board
/GPIO/PB10: J1.8; also elsewhere on the board
/GPIO/PE9: J1.6; also elsewhere on the board
/GPIO/PF8: J1.4; also elsewhere on the board

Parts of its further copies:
J6: Conn_02x05_Odd_Even; PinHeader_2x05_P1.27mm_Vertical_SMD; PartNo 20021121-00010C4LF

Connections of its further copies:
/DebugInterface1/3.3V_VDD: J6.1; also elsewhere on the board
/DebugInterface1/NRST: J6.10; also elsewhere on the board
/DebugInterface1/SWCLK: J6.4; also elsewhere on the board
/DebugInterface1/SWDIO: J6.2; also elsewhere on the board
/DebugInterface1/SWO: J6.6; also elsewhere on the board

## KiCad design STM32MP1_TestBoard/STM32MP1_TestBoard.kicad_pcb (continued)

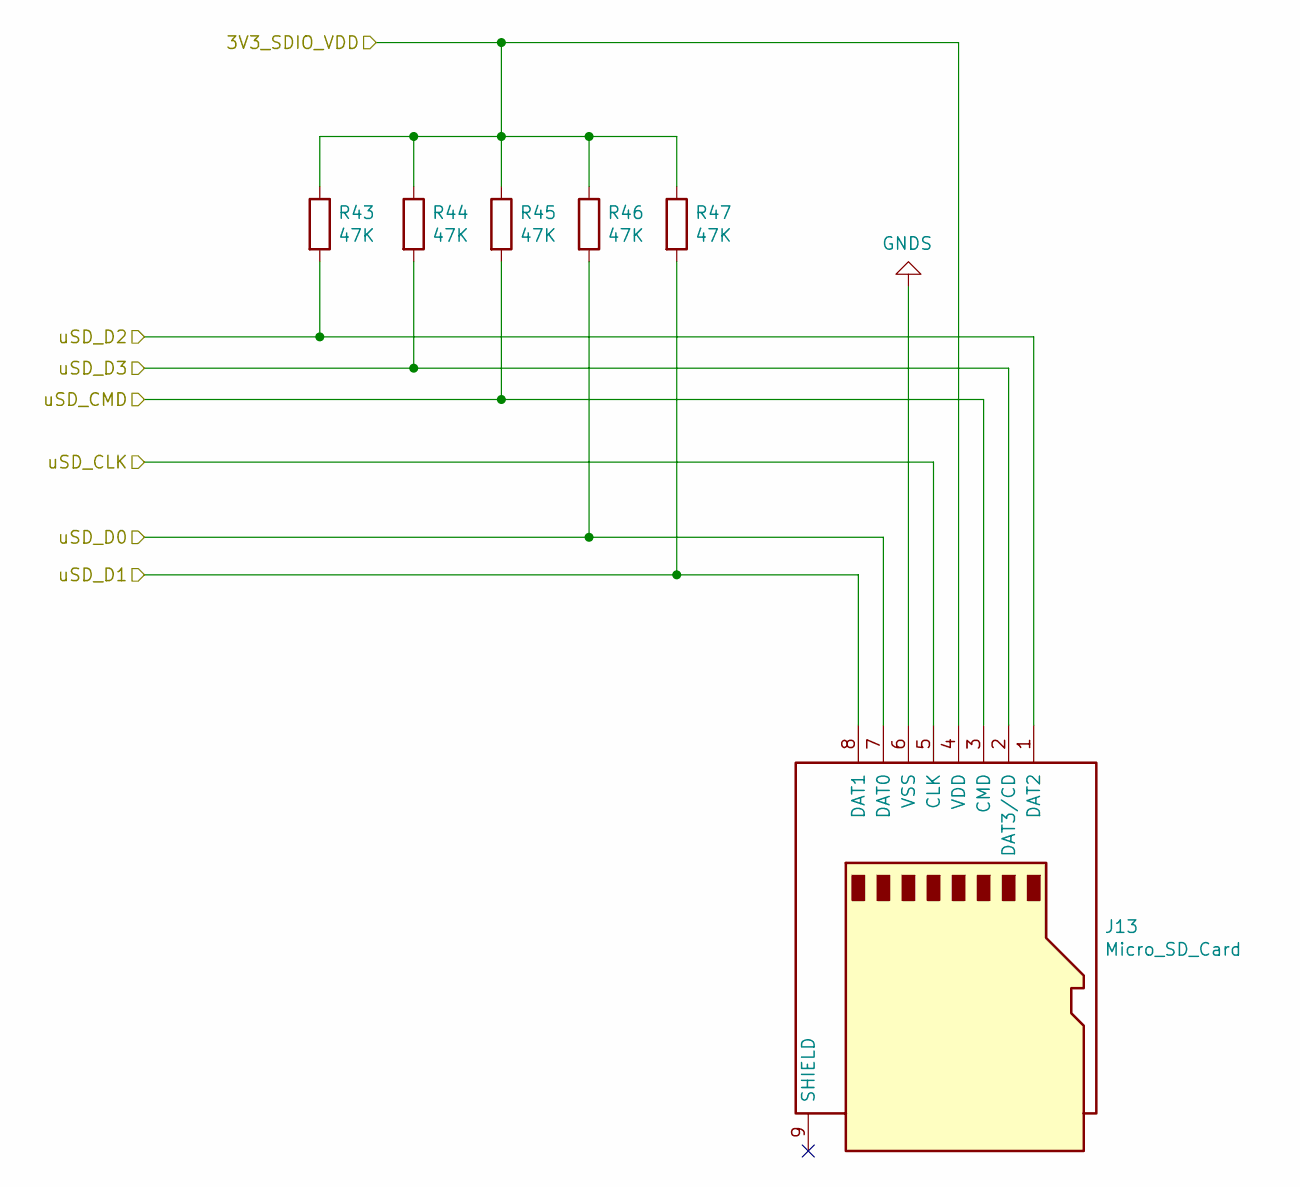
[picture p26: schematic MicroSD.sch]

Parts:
J11: Micro_SD_Card; Molex_SDIO_475710001; PartNo 475710001
R40, R41, R42, R43, R44: 47K; R_0805_2012Metric_Pad1.20x1.40mm_HandSolder

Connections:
/DebugInterface1/3.3V_VDD: R40.1, R41.1, R42.1, R43.1, R44.1; also elsewhere on the board

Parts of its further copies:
J12: Micro_SD_Card; Molex_SDIO_475710001; PartNo 475710001
R12, R13, R45, R46, R47, R48, R49: 47K; R_0805_2012Metric_Pad1.20x1.40mm_HandSolder

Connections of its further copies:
/DebugInterface1/3.3V_VDD: J12.4 (VDD), R12.1, R13.1, R45.1, R46.1, R47.1; also elsewhere on the board
/GPIO/PA0: R45.2; also elsewhere on the board
/GPIO/PB13: R46.2; also elsewhere on the board
/GPIO/PB15: R47.2; also elsewhere on the board
/GPIO/PC12: J12.5 (CLK); also elsewhere on the board

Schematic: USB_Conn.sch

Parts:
J8, J13: USB_B_Micro; USB_Micro-B_Molex-105017-0001
R16, R17: 0R; R_0402_1005Metric_Pad0.72x0.64mm_HandSolder

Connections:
/DebugInterface1/3.3V_VDD: J13.4 (ID); also elsewhere on the board
/GPIO/PA0: J13.3 (D+); also elsewhere on the board
/GPIO/USB_Conn/USB_D2_N: J8.2 (D-); also elsewhere on the board
/GPIO/USB_Conn/USB_D2_P: J8.3 (D+); also elsewhere on the board
unnamed: J8.1 (VBUS), R16.2
unnamed: J8.5 (GND), R17.2

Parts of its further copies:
J14: USB_B_Micro; USB_Micro-B_Molex-105017-0001

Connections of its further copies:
/GPIO/USB_Conn/USB_D1_N: J14.3 (D+); also elsewhere on the board
/GPIO/USB_Conn/USB_D1_P: J14.2 (D-); also elsewhere on the board

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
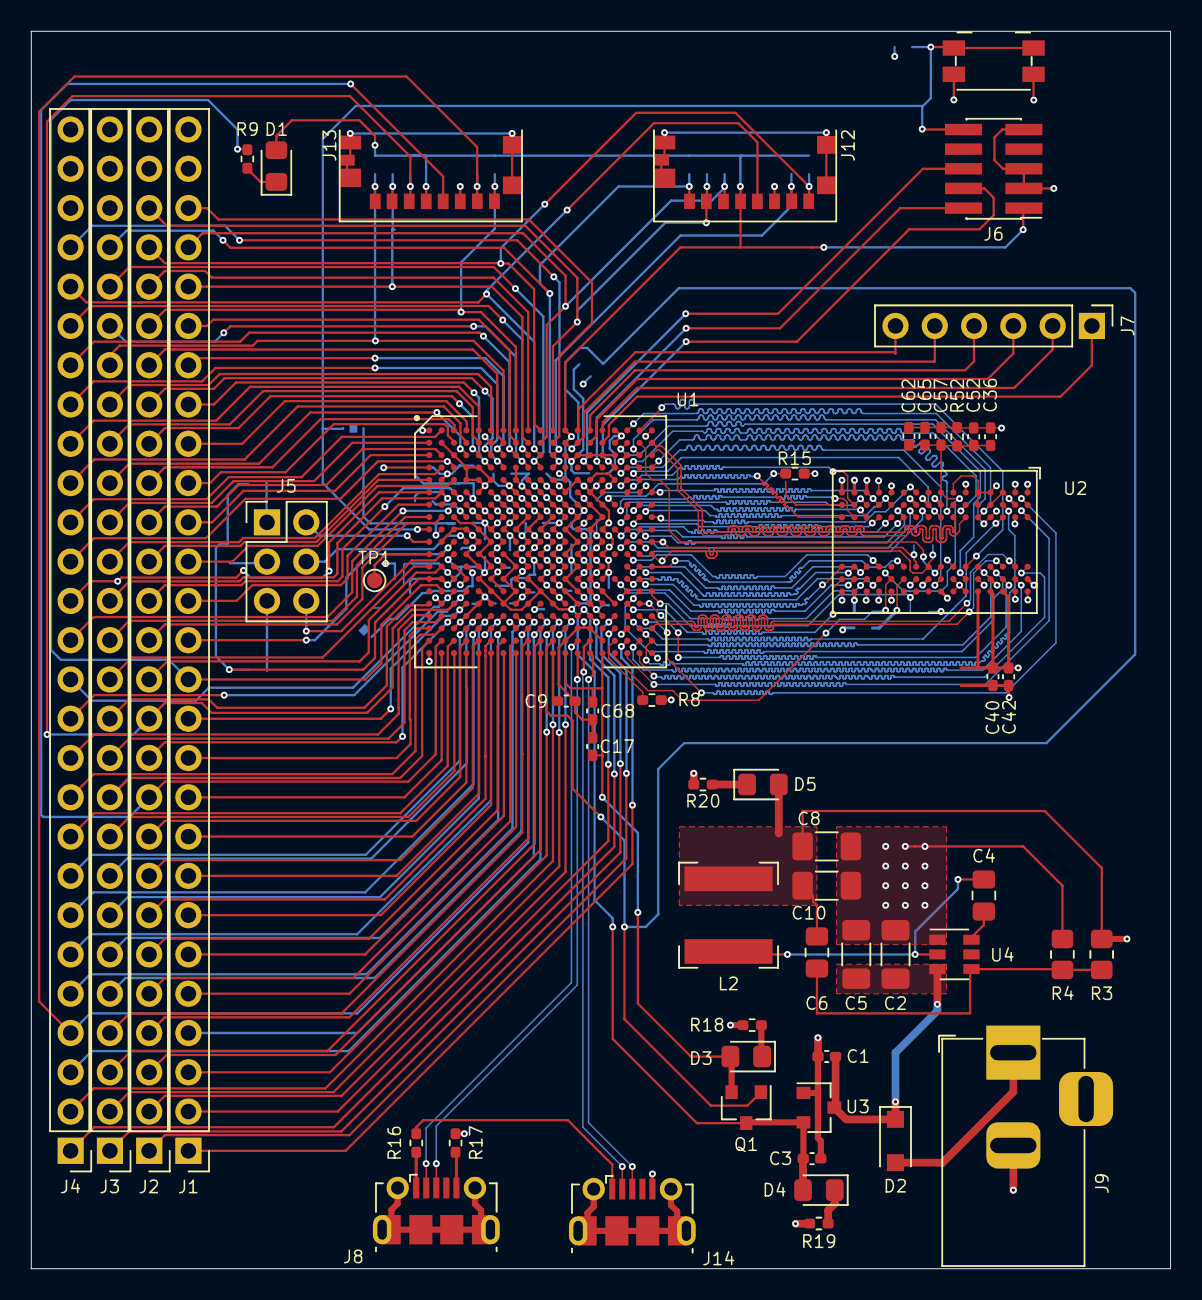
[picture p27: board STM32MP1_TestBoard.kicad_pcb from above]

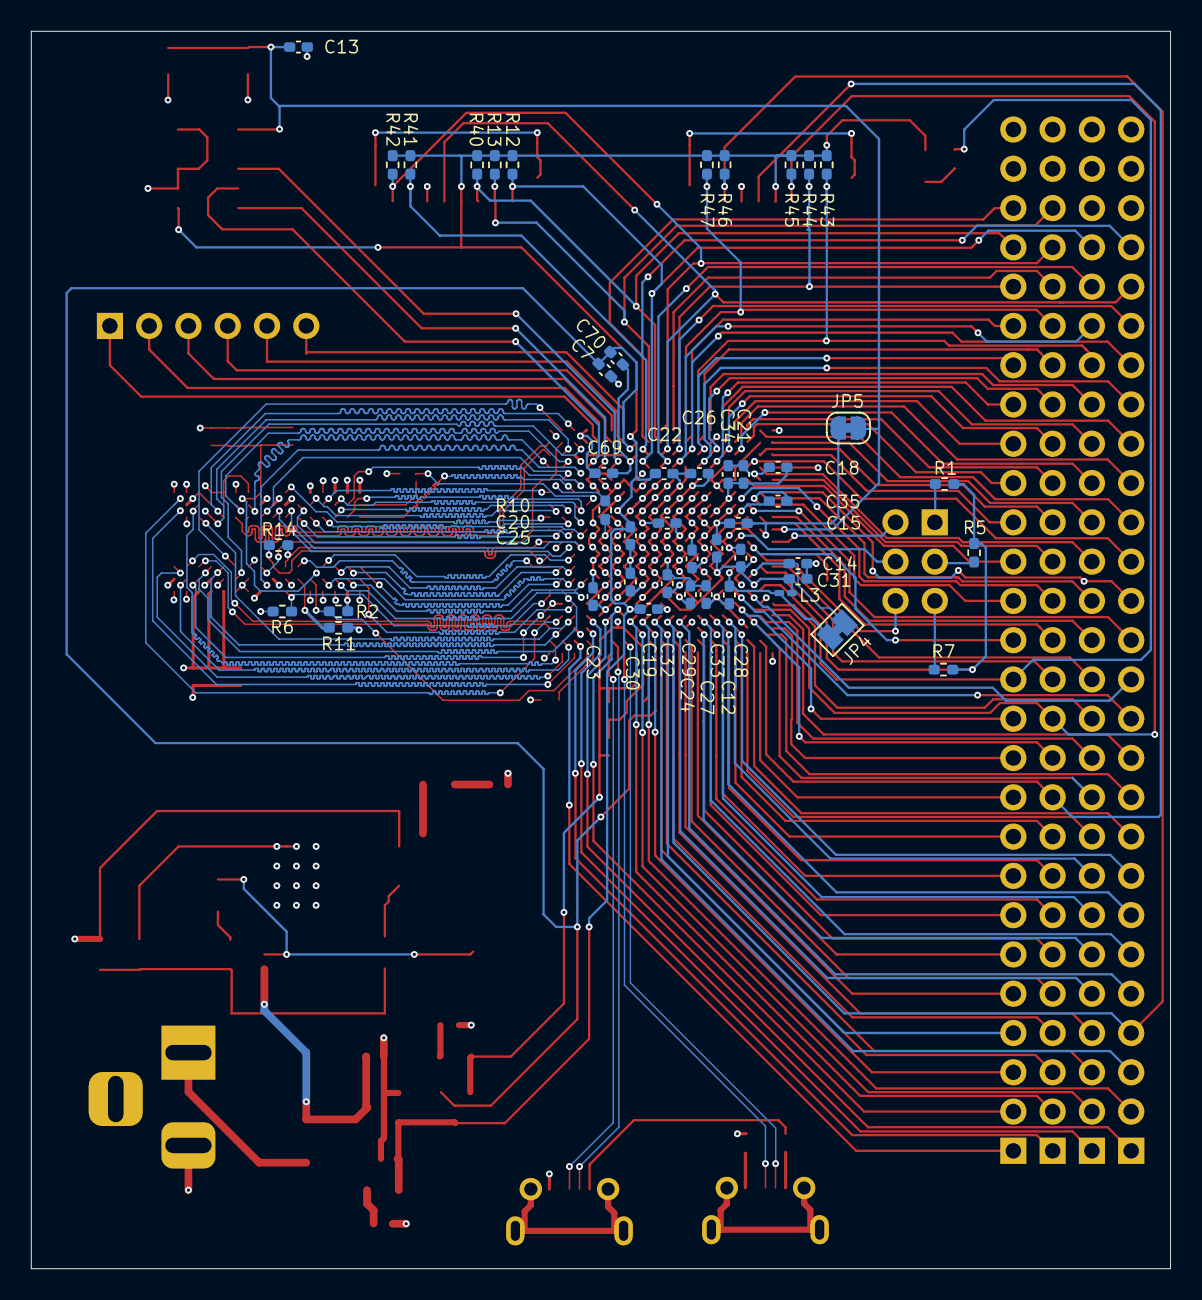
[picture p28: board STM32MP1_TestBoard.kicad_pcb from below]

Board: 4 copper layers, 73.7 x 80.0 mm, 100 parts (46 on the bottom side), 195 nets.

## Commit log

2020-11-14 First draft schema
    [DDR.sch, MicroSD.sch, PSU.sch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]
2020-11-14 updated bom, readme
    [DDR.sch, MicroSD.sch, PSU.sch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]
2020-11-15 swapped smps for ldo
    [PSU.sch, Power_MPU.sch]
2020-11-15 minor schema updates
    [DDR.sch, PSU.sch, Power_MPU.sch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]
2020-11-16 updated netlist
    [MicroSD.sch, STM32MP1_TestBoard.kicad_pcb]
2020-11-16 updated schematic design
    [DDR.sch, DebugInterface.sch, GPIO.sch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]
2020-11-18 layout update
    backup. work in progress
    [DDR.sch, DebugInterface.sch, GPIO.sch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]
2020-11-20 updated to use stm32MP15x symbol library
    [DDR.sch, DebugInterface.sch, GPIO.sch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]
2020-11-30 added traces for sdio, dsi and swd connectors
    [DDR.sch, GPIO.sch, STM32MP1_TestBoard.kicad_pcb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]
2020-12-02 added psu
    [PSU.sch, STM32MP1_TestBoard.kicad_pcb]
2020-12-05 swapped DDR3 high/low strobe diff pairs
    - corrected DRC errors
    [DDR.sch, PSU.sch, Power_MPU.sch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]
2020-12-06 finished RevA draft layout
    - Added MPU bypass caps
    - length tuned DDR3L traces
    [STM32MP1_TestBoard.kicad_pcb]
2020-12-07 updated RevA draft
    - Added outer layer ground planes
    - Added outer layer keepout zones for DDR3 area
    [1050170001.stp, 475710001.stp, DC Power Jack 5.5mm x 2.1mm.STEP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]
2020-12-07 updated RevA draft
    - added silkscreen
    [GPIO.sch, MicroSD.sch, STM32MP1_TestBoard.sch]
2020-12-08 RevA layout final
    [GPIO.sch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]
2021-01-01 updated schematic
    changed STM32MP157xAB to STM32MP157xAC
    [Power_MPU.sch]
2021-01-01 updated schema and bom docs
    [DDR.sch, DebugInterface.sch, GPIO.sch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]
2021-01-10 corrected STM32MP157 footprint
    [DDR.sch, DebugInterface.sch, GPIO.sch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]
2021-01-26 added USART tags to GPIO pins on schema
    [GPIO.sch]
